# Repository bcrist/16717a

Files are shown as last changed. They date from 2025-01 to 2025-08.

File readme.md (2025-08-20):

# 16717A Logic Analyzer Redux

The HP/Agilent 16700A/B and 16702A/B logic analyzer mainframes were originally released somewhere between 1998 and 1999, and though they have now been obsolete for many years, they can still be useful for hobbyists who need to debug digital circuits with large parallel buses (especially the homebrew CPU community, who build computers from scratch, often using nothing but 7400-series logic and parallel SRAM chips).  These "boat anchors" were the last logic analyzers produced which do not use commodity PC hardware or run Windows; instead they run HP's unix variant (HP-UX) on a 150MHz PA-RISC processor.  All the operating system and analysis software is still available, and can be run from a SCSI hard drive emulator like SCSI2SD or ZuluSCSI.  And since it is just an X-windows application, you can run an X server on a modern machine with a high resolution monitor and then view the analysis software on that instead of being limited to the built-in 1024x768 LCD.

The actual triggering, sampling, and storage of waveform data is done on up to five modules.  HP/Agilent produced a variety of these, but the ones most commonly found today are:
* 16710A, 16711A, 16712A: up to 128k sample depth, 104 channels (max. 208 with 2 modules), 100MHz state analysis, 500MHz timing analysis
* 16715A, 16716A, 16717A: up to 4M sample depth, 68 channels (max. 340 with 5 modules), 333MHz state analysis, 2GHz timing analysis (except 16715A)

There's only two different PCBs used for these and the lower model numbers are effectively just software limited to a lower memory depth and can be "upgraded" by adding or removing a resistor (apart from the 16715A which lacks all the timing zoom chips).

All the 167xxA modules had plastic sliders on the bottom to prevent damage to any components on that side if not installed carefully.  Unfortunately, these rails were attached with a foam/rubber adhesive that over time either becomes corrosive, or absorbs water from the air which then becomes corrosive.  This has been documented extensively on the [EEVblog forums](https://www.eevblog.com/forum/repair/series-defect-on-agilent-167xx-boards/).  It seems this corrosion begins to appear pretty reliably around 5 years after the board was made.  As of 2025, any board which has not already had the rails removed is almost guaranteed to no longer be fully functional.  Depending on the damage, it may still be possible to repair, but if any corrosion managed to work its way into a via connecting to one of the internal signal layers, it will likely be unfixable.  I have a handful of 16717A boards like this, and multi-layer PCBs have become surprisingly affordable in recent years, so I decided to desolder all the components from one and sand down the PCB layer by layer to reverse engineer it.  You can find the scans from this in the [scans](./scans/) directory.

# Reference Design
In the [original](./original/) directory you can find my reverse-engineered version of the 16717A that is as close to the original board design as I could make it based on my scans.  Due to distortion, there may be some errors in component and trace placement, however it includes all test points from the original and should be useful when debugging failed 16717A boards.  Unfortunately there are a number of signals that I can't confidently guess at their purpose, so I just named them things like `CTRL1` etc.

# Redux Design
I wasn't happy with a number of things about the original design, so I decided to create a modified version that I think should be more reliable, and if you're going to have these boards made, it's the one I would suggest.  This version is pictured above, and the details can be found in the [redux](./redux) directory.  As of this writing, ordering a set of 5 PCBs from JLCPCB will cost between $260 - $310 depending on solder mask color and shipping selections.

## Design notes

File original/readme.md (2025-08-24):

# Original 16717A PCB Reproduction

Note: While this board design is meant to match the original as closely as possible, I have not had it manufactured or tested.  Use at your own risk.

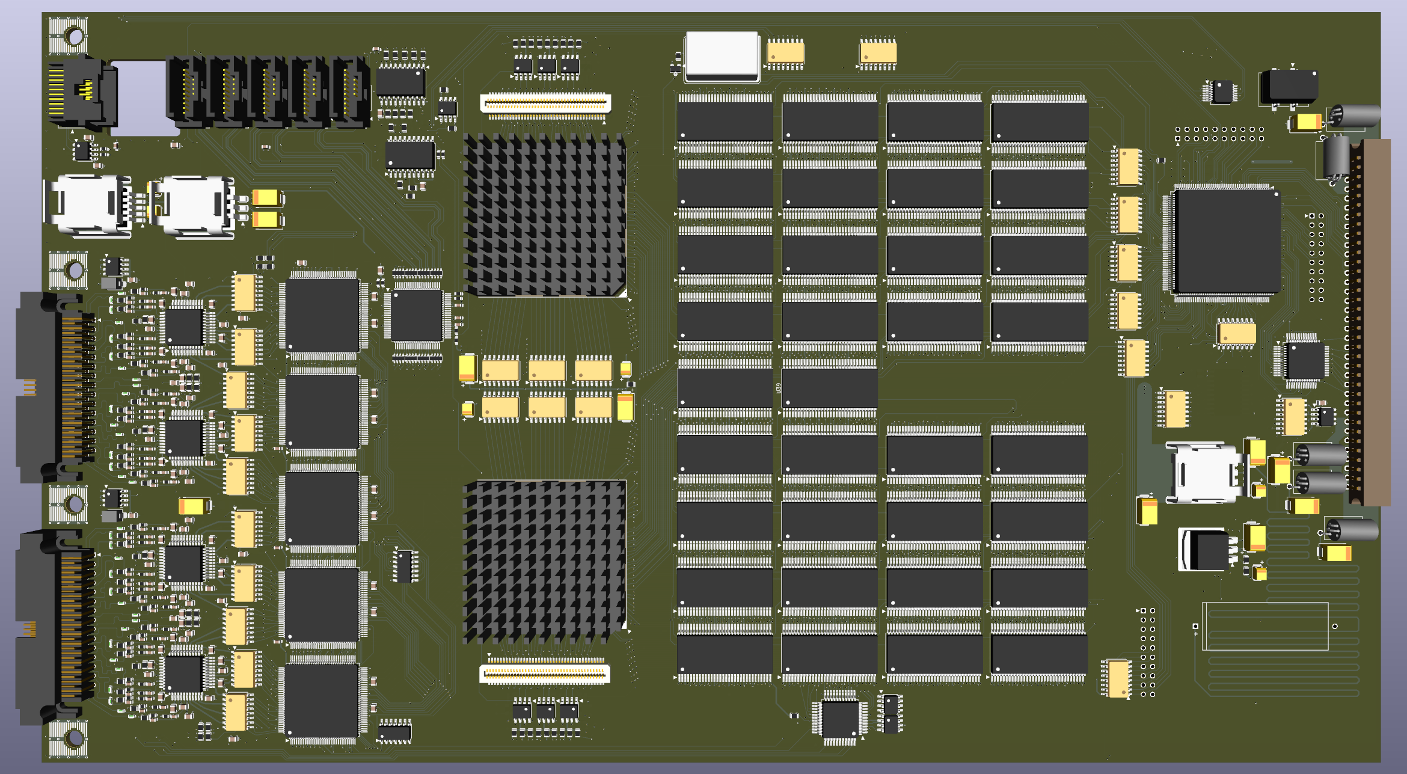
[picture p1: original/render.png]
3D Render


# Theory of Operation

You may also be interested in reading the official "Theory of Operation" section of the [Agilent manual](https://docs.alltest.net/manual/Alltest-Agilent-Keysight-16717A-ServiceManual-21826-.pdf), starting on page 146.  However I am hesitant to take anything it says at face value, because they describe some things which simply cannot be true based on the actual 16717A hardware.  I suspect that they probably started by copying the "Theory of Operation" section of a previous board (16712A maybe?) and missed some changes to how things work on the newer boards.  I'll try to note these issues below.

## Stackup
The 16717A uses an 8-layer board, four of which are signals:

* Layer 1 (top): components, signals
* Layer 2: ground
* Layer 3: +5V, -5.2V, ground
* Layer 4: signal
* Layer 5: signal
* Layer 6: +3.3V, -3.3V
* Layer 7: ground
* Layer 8 (bottom): components, signals

I wasn't able to determine individual core/prepreg thicknesses, but it didn't feel like any particular layers were significantly thicker than others, so I'm guessing the dielectric thickness of all FR4 layers is somewhere around 0.2mm.

## Input Conditioning & Comparators
Each signal coming in from the probe pods is length-matched and goes through an 0603 component which I can't identify, but they appear to be some kind of inductor.  At first I thought these might be fuses, but after looking at them under a microscope, it's clear they feature a spiral planar coil with 6 turns.  My LCR meter just says they're 0.1 ohm resistors.

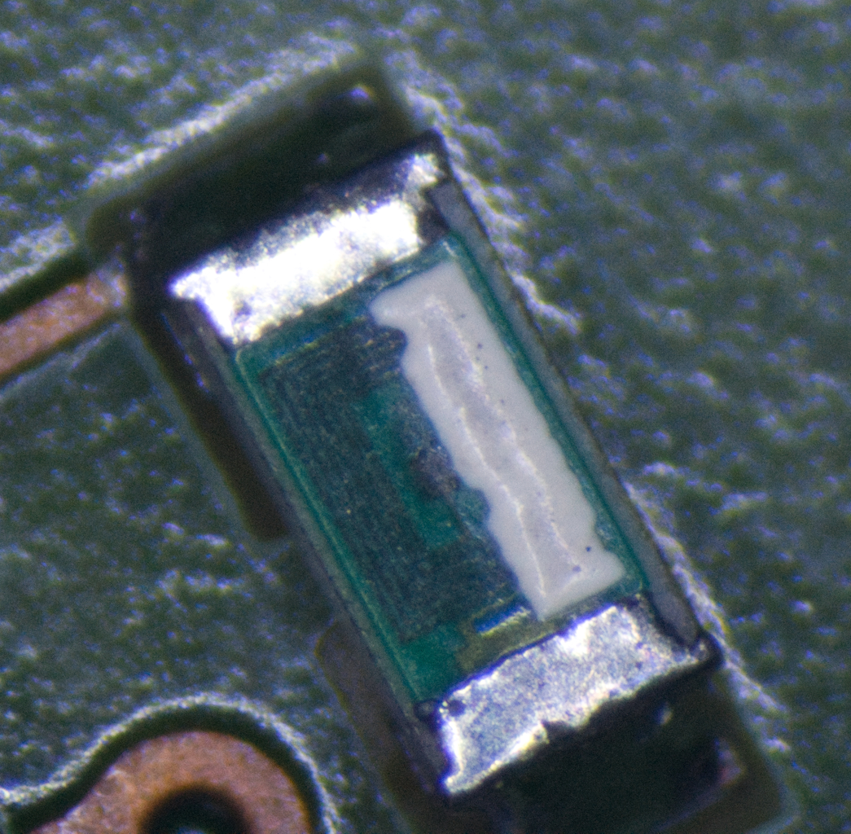
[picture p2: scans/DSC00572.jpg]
Unknown Inductor


Next each signal is terminated to ground through a 10k resistor, and further conditioned by several RC networks before being fed into one of 8 high speed comparator ASICs (part number 1NB4-5036).  Each chip has 9 signal inputs (8 data bits + 1 clock).  Each probe pod has 16 data bits and only 1 clock, so only half the comparators actually use all the inputs; the others have one input grounded.  There is also a test clock input, and when enabled it overrides the signals on all of the inputs.

The reference voltage for each chip can be configured independently, coming from an AD7841 8-channel DAC.  Interestingly, while the DAC has 8 outputs, each corresponding to one comparator chip and half of a pod's data signals, it seems there's no way in software to set half of a pod to a different threshold than the other half.

The outputs from the comparators are a rather strange ECL variant which uses `Vcc` at 3.3V and `Vee` at -5.2V.  `Vbb` is therefore approximately the same as for LVPECL; around 2.1V.  The clock signal outputs are complementary (i.e. differential) and all others are single-ended.

## Probe Power & I2C
Each pod connector receives 5V power via a TPS2011 high-side switch.  This provides current limiting in case of accidental short-circuit, and allows the power to be turned on or off as needed.  Each pod connector also contains an I2C bus, though I don't think the standard 40-pin probe cables actually connect anything to it.  The I2C bus is controlled by a PCF8584 and an analog switch to control which probe connector is currently being interrogated.

## Control FPGA & Backplane Interface
Most of the operation of the 16717A module is controlled directly by an Actel A32140DX FPGA.  The FPGA interfaces with the backplane bus, generates all of the DRAM refresh timing and control signals, and controls the two main data buses (the 16 bit memory data bus and 8 bit zoom data bus).  It also controls the comparator reference voltage DAC (through the memory data bus).

When used in a multi-module configuration, the FPGA on the master module can communicate with the FPGAs on the other modules using a 2 bit bus connected over the 20-pin ribbon cables.  This is probably some kind of serial connection; probably just a half-duplex SPI (clock + data).  It could be I2C, but if there were room to fit an I2C controller in the FPGA, they wouldn't need to use an expensive PCF8584 for the probe connector I2C bus.

The 16500A backplane bus had 8 dedicated bidirectional data lines and separate unidirectional address lines.  The 16700A service manual notes that the 16700 bus is backwards compatible with that, but has been extended to allow a 16b mode with multiplexed data/address.

There is also an 8b open collector bus, which I believe is what the service manual refers to as the IMB (inter-module bus) and is used for synchronizing triggers between modules.  This bus is interfaced with a 74FB2040 BTL buffer chip.  The FPGA drives the FB2040 TTL-level output signals, while the TTL-level input signals are sent to both of the acquisition ASICs.

## Timing Zoom Acquisition[^1]
The outputs from the comparators go through some custom resistor networks which split each signal into two.  One of the signals goes directly into the Timing Zoom chips (1NB4-5040).  These five chips each have 14 differential inputs.  For the single-ended signals (i.e. everything except the clocks) the inverting input is fed from the corresponding comparator's `Vbb` output, after it also goes through the same kind of resistor network as the signals.  I suspect these chips are mostly just high speed SRAMs with an address counter to fill them up automatically and some interface circuitry to allow them to be read out from an 8 bit bus.  The chips use only 3.3V power, and it would seem the 8 bit "zoom data bus" uses LVCMOS signaling.

Most of the zoom data bus signals are shared in common across all five chips, but each zoom acquisition chip does have one dedicated chip select (or possibly output enable?) signal, as well as a signal that's connected to one of the bits of the zoom data bus (but a different bit for each chip).  My best guess is that the latter signals are used to allow "multicast" commands to be sent to multiple chips at the same time.  This data bit signal is also delivered to each chip after being gated by a 74LVC08 chip, combining them with one of the shared control signals.  I have seen pictures of an early 16716A prototype board where the 74LVC08 chips were added dead-bug style with bodge wires, so apparently these are only there to work around some bug in the 1NB4-5040 silicon.

## Timing Zoom Clock Generation & Distribution[^1]
In order to ensure that all the timing zoom chips are synchronized (including potentially on multiple modules), they need to be clocked from the same source.  That source is a 101MHz PECL oscillator.  The signal is level shifted to LVPECL through DC-blocking capacitors and an LVPECL differential receiver, and then goes through a SY89421V PLL in 10x mode, resulting in a 1.01GHz differential LVPECL output.  That signal then goes to the HP 1821-4731 clock distribution ASIC, which buffers it out to each of the 20-pin ribbon cable connectors in the corner of the board.  It then comes back via the right-angle 20-pin connector, through another LVPECL buffer, and right back into the clock distribution ASIC again.  When using just a single board, this might seem silly, but it means that when using multiple modules, the clock from the "master" module is delivered to the clock distribution chip on each module with exactly the same propagation delay.  Finally, a pair of differential clocks are delivered to each of the five 1NB4-5050 chips.  Since the zoom clock is only 1GHz, but the timing zoom feature captures at 2GS/s, it might be that one of these clocks is just a 180-degree out of phase copy?  I don't have a scope fast enough to capture these signals, so I'm not sure.

The timing zoom distribution chip appears to be a fully bipolar design, using 5V ECL signaling for everything, except instead of the usual 5V PECL or -5V NECL schemes, it uses 3.3V `Vcc` and -1.7V `Vee`.  This is partly necessary because the zoom acquisition chips are only capable of receiving 3.3V signals, but as to why they didn't just design the part to use LVPECL with `Vee` connected to ground, I cannot guess.  Perhaps they originally designed this chip for something else where `Vcc` was 5V?

The clock distribution chip also connects to the zoom data bus, and has a bunch of control signals coming from the FPGA, but since these signals use normal TTL/CMOS signaling, they need to go through some resistor networks to massage them into something that the single-ended ECL inputs can detect.  Because of this, it is likely that this chip can't write anything back to the zoom data bus, it's likely only used to configure the zoom acquisition frequency (there is a configurable divider somewhere in there) and possibly configure how many clock pulses to generate when triggered.

There is one apparently ECL output from the zoom distribution chip.  It goes to an LM311 with the negative input held at 2.1V, and the result gets sent to the FPGA.  I have no idea what this might be used for, but it must not be anything timing sensitive, since the comparator will not react very fast.  Perhaps it's an error signal used to detect a failed oscillator/PLL?

Finally, the zoom clock distribution chip receives a signal from each of the two regular acquisition ASICs.  I suspect this is used to gate the zoom clock until the trigger condition has been detected.

## Test Clock Generation & Distribution
In addition to the differential zoom clock, the 20-pin ribbon cables also distribute a pair of LVNECL test clocks from the master module to each module.  This signal originates from the 100MHz backplane clock, divided down to either 50MHz or 25MHz by an MC10EL34 and MC100LVEL14.  Once on each module, the clocks go through a voltage divider and are sent into each of the comparator chips.  The test clock allows self tests to verify of most of the signal paths without needing any external equipment to inject signals.

## Acquisition ASICs[^2]
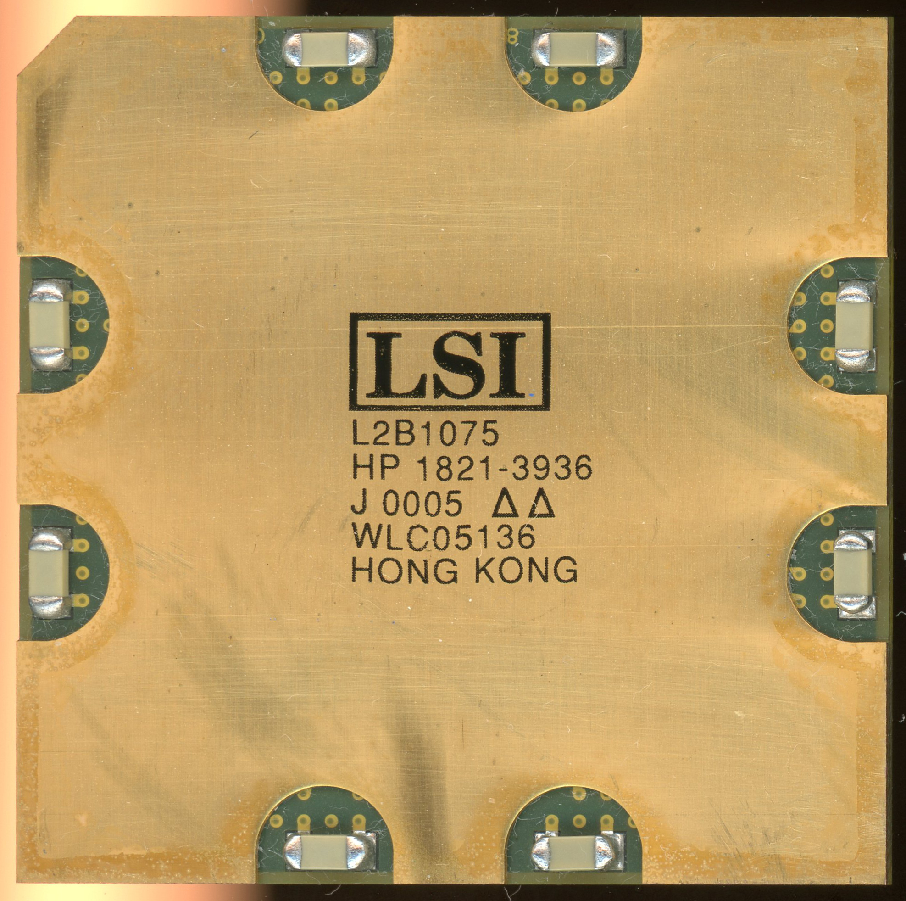
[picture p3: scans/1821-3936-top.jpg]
Top

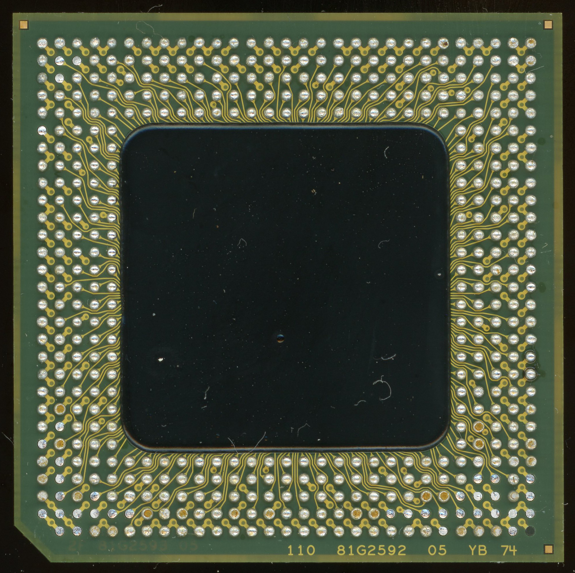
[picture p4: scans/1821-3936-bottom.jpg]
Bottom

As mentioned above, the ECL outputs from the comparators are split in two, with one signal going to the zoom chips, and the other being routed through 80-100mm of microstrip to one of the two HP 1821-3936 chips (pictured above).  Each ASIC is responsible for sampling 34 channels (32 data + 2 clocks).  The clock signals use differential signaling, while the data signals are single-ended.  The `Vbb` voltage from each comparator is delivered to the acquisition ASIC, but pulled up slightly closer to 3.3V via a 1K/10K voltage divider, so instead of ~2.1V, the ASIC sees ~2.3V, and I'm not sure why.  The ECL signals should swing between 1.7V~2.5V, so 2.3V is likely still fine as a threshold as long as there isn't much noise.  Maybe the fall time of the single-ended ECL signals is significantly slower than the rise time (due to the emitter follower in combination with 50 ohm transmission line) so they wanted a threshold as close to `Voh` as possible?

The service manual states "All four state acquisition clocks are sent to each acquisition IC, and the acquisition ICs generate their own sample clocks," however this is not true; each acquisition ASIC only directly receives two of the pod clocks.  My best guess is that they're speaking somewhat metaphorically, and the other two are "sent" indirectly via the inter-module communication buses discussed below.

It appears that each clock and data input goes through an independently programmable delay line to account for any propagation delay differences between channels.  `pv`'s `calTest`  indicates that the delay can be adjusted in increments of 114ps.  The service manual has this to say:

> Every time the user selects the RUN icon, the acquisition ICs individually perform a clock optimization before data is stored.
>
> Clock optimization involves using programmable delays in the acquisition ICs to position the master clock transition where valid data is captured. This procedure greatly reduces the effects of channel-to-channel skew and other propagation delays.

It's unclear if this is done using the test clock enabled, or with actual signal data, but either way, this would seem to imply that trace length matching the input signals isn't necessary (at least after the comparator outputs), but it seems like the 16717A board designer did try to do length matching anyway.  Or rather, they superficially tried, but then gave up.  The signals for each ASIC are mostly length matched amongst themselves, but the ones on the left side are all about 20mm shorter than the ones on the right side, and even within each side, there are a few outliers that are over 5mm different from the other traces.

The ASICs are configured using the 16 bit memory data bus.  This would include things like the aforementioned delay lines, setting up the triggering and state clock FSAs, etc.

There are a number of control signals which go between the FPGA and the ASICs, and I mostly have no idea what specifically they are used for, but some of them are probably chip select, read/write, and clock for reading/writing registers over the memory data bus.

The ASICs also receive the 100MHz backplane clock. `pv`'s `bpClkTest` indicates that these chips contain a PLL capable of generating at least a 166.67MHz clock from this signal.  It's unclear what reference `bpClkTest` is using to measure these frequencies, since the comparator test clock is also based on the backplane clock.  Perhaps one of the control signals from the FPGA is a copy of the FPGA clock?  The service manual mentions that in (non-zoom) timing analysis, a 4-phase 125MHz clock is used, and later mentions:

> Also, the Test and Clock Synchronization Circuit generates a four-phase 125-MHz sample/synchronization signal for the acquisition ICs operating in the timing acquisition mode. At fast sample rates, the synchronizing signal keeps the internal clocking of the individual acquisition ICs locked in step with the other acquisition ICs in the module.

This is patently false.  There is no stand-alone PLL or oscillator capable of generating even one 125MHz clock, let alone a four-phase clock, and the 50/25MHz test clock cannot be delivered to the acquisition chips at the same time as real signals are being observed, so if such functionality exists, presumably these clocks are generated from the PLLs internal to the ASICs, based on the 100MHz system backplane clock.

The backplane contains an 8 bit BTL bus which I suspect is used when you set up "chained" triggers between isolated modules.  These signals can be driven from the FPGA, and are buffered and sent to both of the acquisition ASICs.  I believe this bus is what is used for `pv`'s `flagTest` and possibly also the `armTest`.

## Inter-Module Communication[^2]
The two acquisition ASICs communicate with each other, and with the ASICs on other modules, via a combination of single-ended parallel buses and differential serial buses.

The parallel signals are either two 24 bit buses (based on their routing and pin assignments on the BGA packages) or three 16 bit buses (based on the output of `pv`'s `icrTest`).
Half of the bits are routed between modules on the left 80 pin mezzanine connector, and the other half on the other connector.
The signals are terminated with pullups to 1.5V, and there is a resistor network set up to provide a reference at 2/3 of this termination voltage, which makes it look a lot like GTLP signaling.  Although snooping on some of the signals while running `icrTest` shows that they are driven all the way to 0V when low.  I don't have much experience with GTLP, but my understanding is that `Vol` should be more like 0.5V, so I'm not sure if they're really using GTLP drivers or just something similar.
Oddly, the 1.5V termination voltage is generated from a linear regulator which receives 5V through a long, winding PCB trace.  I guess the intent here was that it would act like an inductor/transmission line and help reduce noise?  There is also a footprint for a huge axial electrolytic cap on the plane side of this 5V trace.  It is unpopulated on production boards, but the 16716A prototype photos show it populated.

The differential serial signals are grouped into two sets of three differential pairs, and have separate transmit and receive pins on the ASICs.  The left ASIC appears to only be capable of transmitting to the three signals on the left mezzanine connector, and the same with the right ASIC and right mezzanine connector.  The signals from the mezzanine connectors are buffered by LVPECL receivers and then routed to both ASICs, so every ASIC can listen to both "sides" of the system, even if they can only transmit on one side.  The six pins that are used to transmit on the left side are different from the six pins used on the right side, and the "unused" set from the other side of the chip is connected across to the other ASIC, but not to the mezzanine connectors.  Each ASIC "knows" whether it is left or right, so it's possible these signals are six single-ended GTLP signals rather than three complementary pairs.  It's also possible that these could be used to allow the left chip to transmit on the right mezzanine connector's differential pairs, using the right ASIC as an intermediary, and vice-versa.

It appears someone tried to length-match the differential signals from the mezzanine connectors (after going through the LVPECL buffers) so that the delay to the left and right chips is identical.  But they only matched two of the three pairs.  I suspect that these signals correspond to the "master/slave/psync" clocks mentioned in the `clksTest` description in the service manual.  Unfortunately there's exactly no discussion of what these terms mean.  One might suppose that master and slave correspond to whichever clock is configured as master/slave in the GUI, but what does "psync" stand for?  Phase synchronization maybe?  If so what exactly does that mean?

## Sample Memory
Sampled state data is stored in dual port DRAM chips (OKI MSM5416283-50), storing 4Mbit each.  There are 34 total chips (not 18 as the service guide incorrectly says) for a total of 2M samples when using all 68 channels, or 4M samples if only using half the channels.  The chips are split evenly between the two ASICs, with 17 chips connected to each via nine independent "ports," with each port consisting of 16 data bits and a clock signal.  Eight of these ports are attached to the serial access port of two memory chips (i.e. two banks), while the final port is only attached to one chip (one bank).  This means the theoretical maximum write bandwidth is 7200 Mbit/s/ASIC.  At a state clock frequency of 333MHz, with 34 channels enabled, 11322 Mbit/s would be needed, so apparently they're either overclocking these chips, or else very high clock frequencies only work with some channels disabled.

The random access DRAM port, as well as all the memory control signals, are controlled directly by the FPGA, not the acquisition ASICs.  Most of the control signals are shared in common across all 34 chips, except RAS (shared by groups of 4 or 5 chips) and CAS (independently controlled on every chip) and the QSF outputs (only connected for each ASIC's port 9 chip).

[^1]: Timing Zoom circuitry is not populated on 16715A boards.
[^2]: The two HP 1821-3936 ASICs are mostly black boxes, so this section contains a lot of supposition and guesswork.

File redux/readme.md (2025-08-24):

# 16717A Redux

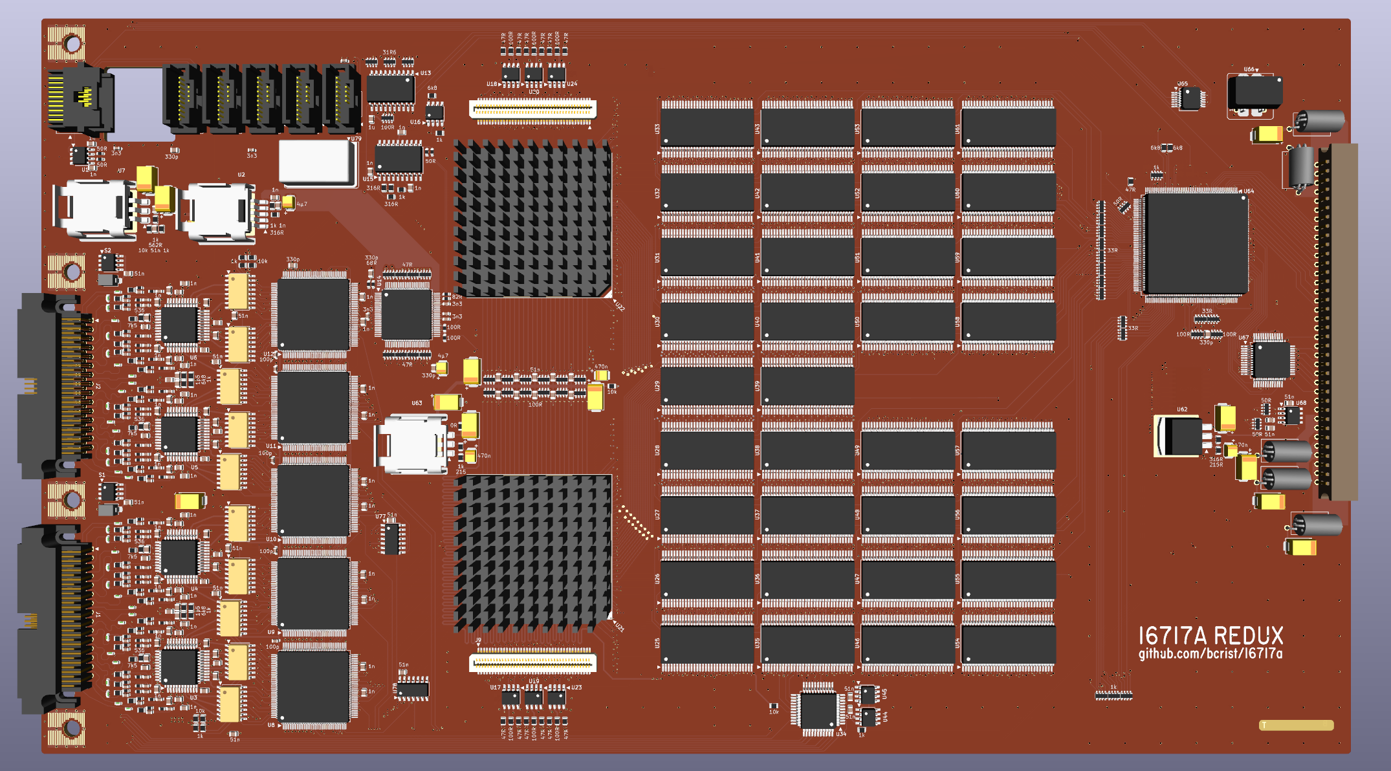
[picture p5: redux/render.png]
3D Render


# Quick Stats
* Dimensions: 366.75mm x 206mm x 1.6mm
* 10 layers
* 1250 components
* 9627 total pads
* 5392 total holes
* 3803 ~ 5048 filled & capped holes

# Tools

I would not recommend attempting to build one of these boards unless you have and know how to use the following equiment:

* 70W+ soldering station (I highly recommend something compatible with Hakko T12/T15 or JBC C210/C245 tips)
* IR preheater or temperature controlled hot plate (at least 100mm square)
* Hot air station (e.g. Quick 861DW)
* 1.27mm pitch BGA reballing tools (balls, stencil, etc.)
* Optical stereo microscope with 20x or higher magnification
* 22L ultrasonic cleaner (or larger; basket should be larger than 21cm x 37cm)

# Stackup

While reverse engineering the 16717A I noticed a lot of potential signal integrity issues:
* Most signals on the inner layers use +5V or +3.3V as a reference plane, but that is often not a power rail associated with the source and/or destination chips.
* Many signals move between front/back layers through vias without any nearby return path via.
* Many signals change between layers with different reference plane potentials without any nearby decoupling caps between the planes.

I'm sure that HP did a ton of testing to ensure there were no real world performance or EMI issues because of this, but since I don't know exactly what FR4 stackup they used, nor the dielectric constant of their core/prepreg layers, I decided it would be better to rework some things and go to a 10-layer design instead.  For small quantities of large size boards, 10-layer boards through JLCPCB are only a little more expensive than 8 layers (relatively speaking), and their default stackup for 10 layers is a bit nicer as well.

Here is the layer ordering I chose:

* Layer 1 (top): components, signals, -1.7V
* Layer 2: ground
* Layer 3: signals, +5V, -3.3V
* Layer 4: ground
* Layer 5: +3.3V, +5V, -3.3V, few signals
* Layer 6: +3.3V, +5V, -3.3V, ground
* Layer 7: ground
* Layer 8: signals, -5.2V, +3.3VP
* Layer 9: ground
* Layer 10 (bottom): components, signals

The most important goal here is to ensure that all signal layers are adjacent to ground plane layers.  No two signal layers are adjacent to each other, and all stripline layers have ground on both sides, not just one.  Additionally, since the board is quite large, the ground and power layers are symetrical to avoid any twist/bend from copper imbalance.  The inner power layers (layer 5 and 6), rather than having having one +5V and one +3.3V layer, are routed with mostly identical planes covering only areas that need 5V and +3.3V separately, to avoid coupling noise from one rail to the other.

## JLCPCB Notes

Trace widths were selected assuming JLCPCB's default 10 layer stackup (JLC10161H-2116) with 1oz outer copper and 0.5oz inner copper.  If you choose to have it manufactured elsewhere, you might need to adjust them.  For reference, JLC10161H-2116 uses four 0.2mm cores (Er = 4.6) and five 4.7mil prepregs (Er = 4.16).

All 0.3mm holes should be epoxy filled and capped (JLCPCB should do this by default for 6+ layer boards).

JLCPCB will charge an extra $15 for any design with more than 4000 holes under 0.5mm in diameter.  This is listed on their "special cases" page, but it isn't described very clearly, and at the time of writing isn't included in their automated quoting tool.  To avoid hitting this limit, most power vias in the design have been set to 0.5mm.  All of the 0.5mm holes on the board _may_ be filled and capped, but it shouldn't be a problem if they are not.

Note that even working to avoid the extra drilling charges, JLCPCB will likely charge an additional $7.50 above their quoted price for this board.  After inquiring they informed me this was due to the large number of electrical test points, though they didn't tell me exactly what the limit is before that kicks in; I decided it wasn't worth pursuing that since there's not much I could do to reduce the number of pads in the design anyway.

# Bringup

It is by no means necessary to follow these exact procedures, however if you are concerned about parts having been potentially damaged in removal from the old board, this guide allows incrementally verifying some subsystems with a minimum of time sunk into soldering hundreds of passive components.

Note: I highly recommend checking all power rails for shorts after each step below, before powering up the mainframe.  The 167xx power supplies do not seem to have short-circuit protection.  I once accidentally plugged in an original 16717A "upside-down" and ended up blowing the PSU (and maybe the FPGA on the 16717A too; it wasn't working beforehand so I can't be sure).  I was using a ribbon cable backplane extender, and forgot that the mainframe was sitting on my desk upside down.  doh!  After replacing the PSU the mainframe still works fine, thankfully.  I was afraid I might have blown the backplane interface board as well, but it seems to still work fine.

## 0. Component Harvesting

For the vast majority of the passive components, you can just use new parts of the same value.  Indeed, since I replaced a bunch of resistors and SOIC resistor networks with more modern 0612 (4x0603) resistor networks, you'll need to use new parts for those.  But almost all the semiconductors and connectors used are either custom, obsolete, or expensive, so you'll need to salvage parts from a donor board (presumably non-working only because of trace/via corrosion).  In particular, you'll need:

* Actel A32140DX FPGA.  I recommend removing this with hot air rather than trying to use low-temp solder (e.g. ChipQuik).  These are one-time-programmable parts, so you need one specifically from a 16715A, 16716A, or 16717A; don't use one from another model of logic analyzer or go looking for one on eBay, etc, or you will be disappointed.
* 2x BGA ASICs with heatsinks.  The heatsinks are attached to a brass heat spreader using a thermally conductive "tape".  Heating it up to ~100C with hot air will soften the adhesive, allowing you to begin peeling off the heatsinks with a plastic spudger.  Once the heatsinks are removed, you can use a hotplate or hot air and a preheater to remove the BGAs themselves.  Once removed, clean up the pads and reball with 0.76mm balls.  Be careful not to use too hot an iron or drag it with too much force when cleaning up the pads; the soldermask used is slightly thicker than a normal PCB's, but it seems to be somewhat softer than a normal soldermask as well.
* 8x 1NB4-5036 comparators - custom HP part; can be reused from any HP logic analyzer using 40-pin (non-differential) probes.
* 5x 1NB4-5040 zoom FISO chips - custom HP part.
* 1821-4731 zoom clock distribution chip - custom HP part.
* 34x OKI MSM5416283 dual port DRAM chips - discontinued/obsolete.  On some of my boards, these chips show signs of rust on the pins of these chips, which I don't think is related to the corrosion on the bottom of the board.  I've done my best to clean and re-tin the legs with solder, but it makes me wonder if these will be the weak link that eventually causes most boards to fail once the trace/via corrosion has been removed from the equation.  On the bright side, with 34 of them on each board, sacrificing one board should provide spares to hopefully fix many others.
* SY89421V PLL chip - discontinued/obsolete.
* SN74FB2040 BTL transceiver - obsolete, though still available via Rochester Electronics at $300+ for a few dozen chips.
* AD7841 DAC - still available at time of writing, but costs $75 each in small quantities.
* 2x AD586 voltage references - still available at time of writing, but costs $12 each in small quantites.
* PCF8584 I2C controller - At time of writing, "last time buy" at DigiKey, and costs $7 each in small quantites.  I'm not actually sure if this part is even necessary; AFAIK the probe cables normally used with the 16717A do not actually connect anything to the I2C signals.
* ECL logic chips: 1x MC10EL34, 1x MC100LVEL11, 1x MC100LVEL14, 8x MC100LVEL16.  These are all still available new, but they're quite expensive.
* 12x MRF9511LT1 NPN transistors (SOT-143 packages near the inter-board connectors).  I'm not 100% certain that this is what these are, but based on the package code and "B E E C" on the silkscreen nearby (which matches the pinout of the MRF9511LT1) I'm fairly sure.  Unfortunately these are obsolete, so you'll need to remove and reuse them or find a modern part with similar specs.
* NEL HS-2810 101 MHz oscillator - discontinued/obsolete.  One of my boards has some rust on the case of this oscillator.  If necessary, you could probably make a small daughterboard with a modern 101 MHz oscillator with differential output to replace this.
* SG-615P 19.6608MHz oscillator - discontinued/obsolete, but I have adjusted the footprint for this oscillator so that any 19.6608 MHz oscillator with TTL output should fit.
* 5x through-hole ferrites & 2x SMD ferrites - these could probably be replaced with any other ferrites, but they're not hard to remove and reuse.
* 68x unknown 0603 inductors (green with white stripe).  These are marked as fuses in the schematic but I suspect they're [actually inductors](../original/readme.md).
* 20x 4816P-B07-000 custom resistor networks.  4816P is/was a common series of SOIC resistor networks, but these are a decidedly nonstandard form, with each network containing four independent networks of three resistors each.  They could likely be replaced with discrete resistors, but it would require significant rework to the board layout.  Alternatively, you could probably make a small PCB with castellated pads in the shape of a SOIC-16 with the required discrete resistors.  But I'm just reusing these for now.
* 3x small heatsinks for LDOs.  These could probably be replaced with any other little glue-on heatsinks if you prefer.
* 4x 3M P08-080-SL-A-G mezannine connectors.  These are obsolete, but it may be possible to find some new-old-stock supplies still.  Otherwise, remove them very carefully with a preheater and relatively low-temp hot air.  I found that preheating to 150C and setting my station to 280C worked well.  Unfortunately, corrosion on the bottom on these boards sometimes destroys the gold plating on these connectors' contacts.  Of course, if you don't plan to use the board in a multi-module configuration, you can just ignore these.
* AMP 1-534204-4 backplane connector.  These are technically still actively produced, but are not stocked at any of the usual distributors, and are $19 each even when you order a whole box of 300.  So again, I chose to just remove the old one with hot air.  Alternatively, a regular 2x36 right-angle 0.1" header could be used, but the pins would need to be shifted a centimeter or so towards the front.  There is room for this, but it would require a lot of layout adjustments.
* 25 mil pitch ribbon cable & 6x connectors.  These could likely be replaced with different but similar parts.  If you're buying a non-working 16717A on eBay, etc, make sure to check if the ribbon cable is included.  I've found some of the test equipment dealers remove them inexplicably.
* 2x Probe cable connectors.  I've found some connectors with seem very similar to the ones HP/Agilent used, but not exactly compatible.  There might be some out there, or it might be possible to adjust the layout for a part with a slightly different layout, but the same connector form factor, but it's probably easiest to just salvage the original connectors.  Use kapton tape to avoid melting the part of the connector that peeks out over the edge of the board, then use hot air from the bottom side.  There are a lot of ground pins on these connectors, so using a preheater to bring the ground planes up to 100 or 150C is helpful.
* 4x PEM press-fit threaded nuts & back panel bracket.  These nuts are likely still available, but I'm not sure exactly what model number they are.  I recommend using a screw or standoff to remove these.  Hold the screw with pliers/vice-grips and rock back and forth until the inserts are free.  Note that removal will likely cause damage to the donor board.

## 1. FPGA

The first goal is to get a 16700A/B to recognize the board as a 16717A module, which indicates that the FPGA isn't completely dead, and is able to communicate with the backplane.  The main parts that need to be populated for this test are:

* The AMP 1-534204-4 backplane connector
* The +5V and +3.3V ferrites and bulk capacitors
* The Actel A32140DX FPGA (the large PQFP-208 package near the backplane connector) and some decoupling capacitors
* The 19.6608 MHz crystal oscillator which is the FPGA's main clock source
* Two of the ribbon cable connectors near the front and some associated resistors and capacitors (the FPGA needs these to determine whether it is the master or an extension board)
* The ribbon cable between the previously mentioned connectors

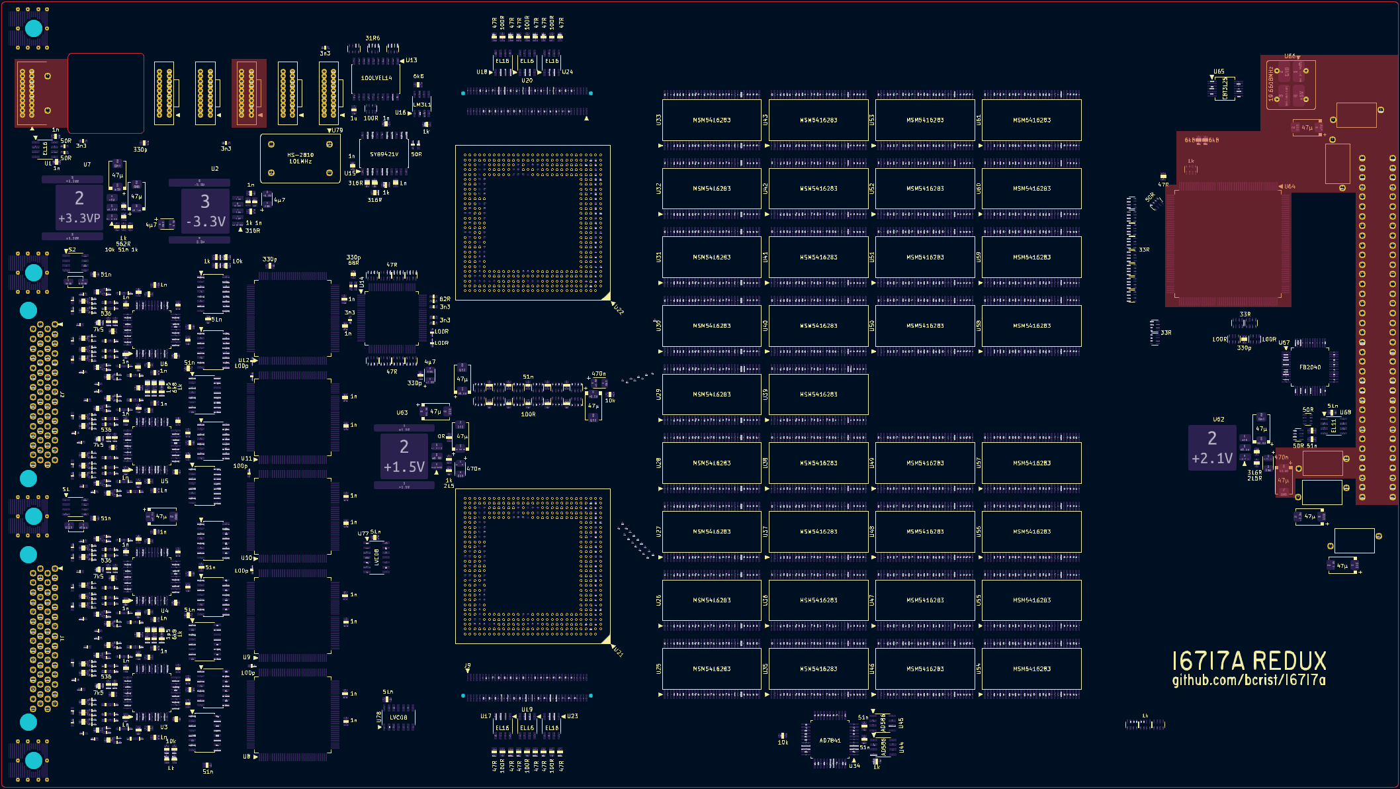
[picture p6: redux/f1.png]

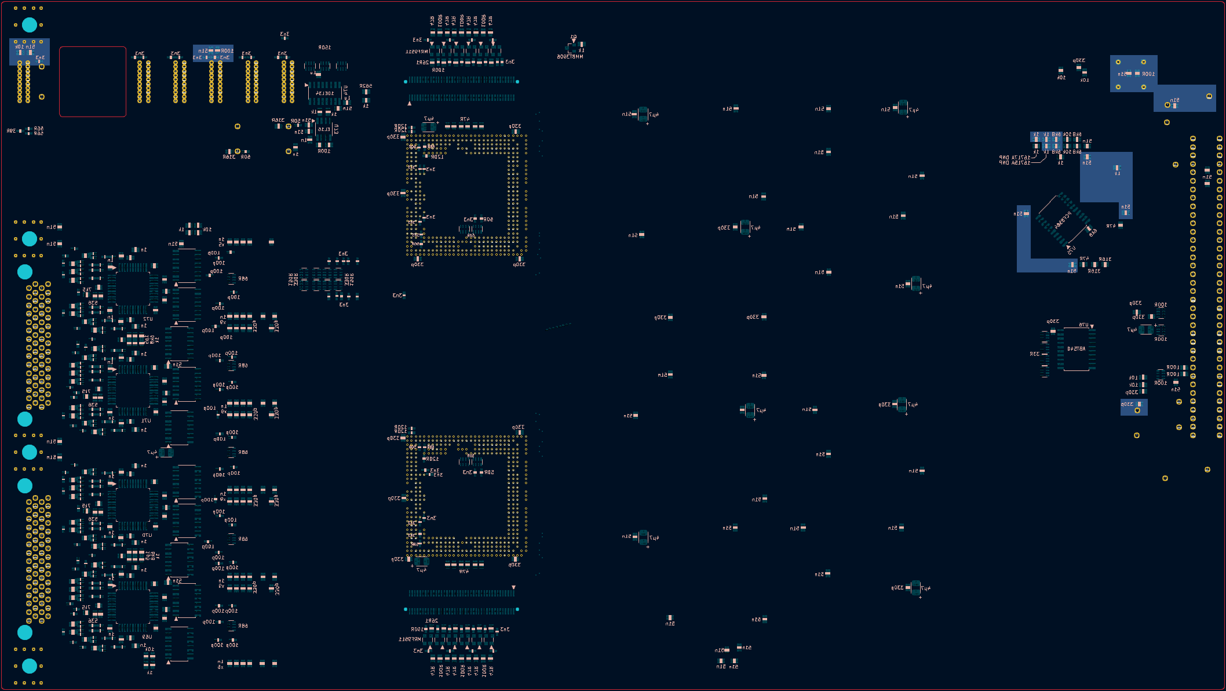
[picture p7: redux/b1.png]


Note: I don't recommend installing the back panel bracket/screws yet.  You can use zip ties to create pull loops for removing the board from a mainframe after testing.

Once these components have been populated, the board should be selectable in `pv`, but all of the tests should fail:

```
$ pv
Shared Memory Segment 204 attached at Virtual Address: 0xc0dbf000
DMA Shared Memory is mapped to Physical Address: 0x4e9b000
Second half of DMA Shared Memory is mapped to Physical Address: 0x4c57000
RPC system Initialized (Program=700016505, Version=1)
pv> l
# Model 16702B
# System Memory=256 Mbytes, PCI device=1, PCI driver=1.01
Mod CPU: System CPU Board
Mod PCI: 16702B System PCI Board
Mod A  : Empty slot
Mod B  : (0x2e) 16717A 333MHz State/2GHz Timing Zoom 2M Sample
Mod C  : Empty slot
Mod D  : Empty slot
Mod E  : Empty slot
Mod 1  : Empty slot
Mod 2  : Empty slot
pv> s b
Module index=B
pv> x modtests
Mod   B: TEST FAILED       # "vramDataTest" (1, 1, -1)
Mod   B: TEST FAILED       # "vramAddrTest" (1, 1, -1)
Mod   B: TEST FAILED       # "vramCellTest" (1, 1, -1)
Mod   B: TEST FAILED       # "vramUnloadTest" (1, 1, -1)
Mod   B: TEST FAILED       # "chipRegTest" (1, 1, -1)
Mod   B: TEST FAILED       # "bpClkTest" (1, 1, -1)
Mod   B: TEST FAILED       # "cmpTest" (1, 1, -1)
Mod   B: TEST FAILED       # "icrTest" (1, 1, -1)
Mod   B: TEST FAILED       # "flagTest" (1, 1, -1)
Mod   B: TEST FAILED       # "armTest" (1, 1, -1)
Mod   B: TEST FAILED       # "vramSerDataTest" (1, 1, -1)
Mod   B: TEST FAILED       # "vramSerCellTest" (1, 1, -1)
Mod   B: TEST FAILED       # "clksTest" (1, 1, -1)
Mod   B: TEST FAILED       # "calTest" (1, 1, -1)
Mod   B: TEST FAILED       # "zoomDataTest" (1, 1, -1)
Mod   B: TEST FAILED       # "zoomMasterTest" (1, 1, -1)
Mod   B: TEST FAILED       # "fisoRedundancyTest" (1, 1, -1)
  Mod B: Unable to Detect WRAP Flag.  Possible Board Fault.
Mod   B: TEST FAILED       # "zoomAcqTest" (1, 1, -1)
  Mod B: Unable to Detect WRAP Flag.  Possible Board Fault.
  Mod B: Unable to Detect WRAP Flag.  Possible Board Fault.
  Mod B: Unable to Detect WRAP Flag.  Possible Board Fault.
  Mod B: Unable to Detect WRAP Flag.  Possible Board Fault.
Mod   B: TEST FAILED       # "zoomChipSelTest" (1, 1, -1)
```

You may see `bpClkTest` report a pass, but it's a false-positive.  If you run the test with debug mode enabled, you can see that the test is only checking for a frequency above certain thresholds.
The PLLs mentioned are inside the acquisition ASICs, so without them populated, it's just picking up random interference.  If it happens to get a "frequency" over 158 MHz, it will consider the test successful.

```
pv> x bpClkTest
  Mod B: Measurement Did Not Complete.
  Testing 100 MHz - PLL bypass mode:
    Slot B, Chip 9: exp: > 9500000, actual: 151783694
    Slot B, Chip 8: exp: > 9500000, actual: 151783694
  Testing PLL at 166.67 MHz:
    Slot B, Chip 9: exp: >15833333, actual: 151783694
    Slot B, Chip 8: exp: >15833333, actual: 151783694
```

You may or may not see the "Unable to Detect WRAP Flag" lines, but if they do appear, they should go away once the remaining passives around the FPGA are populated.

## 2. Acquisition ASICs

By far the most difficult parts to solder are the two ASIC BGAs, so as soon as possible, we want to get them populated and verify that they haven't been destroyed by reflowing.  You may even want to do these before populating the FPGA components in the previous section.

If you're not comfortable reballing and soldering BGAs I'd suggest practicing on something less rare/useful first.  You may find the [`bga_stencil`](../bga_stencil/) directory useful when reballing the chips.  Once reballed, I found that soldering the chips with a hotplate only worked best.  Use polyimide tape to protect the soldermask while clamping the board to a hotplate (clamping is necessary to prevent any warping) and avoid using any hot air from above.  Too much heat can cause the interposer to warp slightly.  If this happens too much it may cause some of the outer balls to not make contact.  Heating only through the board itself helps prevent this.  Wait for the board to fully cool before unclamping it from the hotplate.

After soldering, use a multimeter in diode/resistance/continuity mode to check that each of the test points on the back side of the board has a solid connection to the chip.  There are also a few test points on the top side for signals that never traverse a via.

Once you are confident that all the BGA balls are attached properly, you can install the remaining components for the next test:

* Various resistors and capacitors underneath the ASICs (decoupling, pull ups, etc.)
* Optional: 3M P08-080-SL-A-G board-to-board connectors (these aren't really needed right now, but it may be easier to populate them before the various parts nearby)
* Transistors and ECL buffers near the board-to-board connectors near the edge of the board (used to synchronize clocks between the ASICs)
* Linear regulator for the +1.5V GTLP termination voltage, along with various associated resistors and capacitors
* MMBT3906 transistor and base resistor (allows FPGA to control biasing of inter-module clocks)
* 74FB2040 BTL transceiver, 74ABT540 inverting buffer, and associated passives (forwards async signals from the backplane/FPGA to the ASICs)
* ECL clock buffer for the 100 MHz backplane clock, along with associated passives and the -3.3V power rail passives
* Some additional passives near the FPGA, related to ASIC control signals

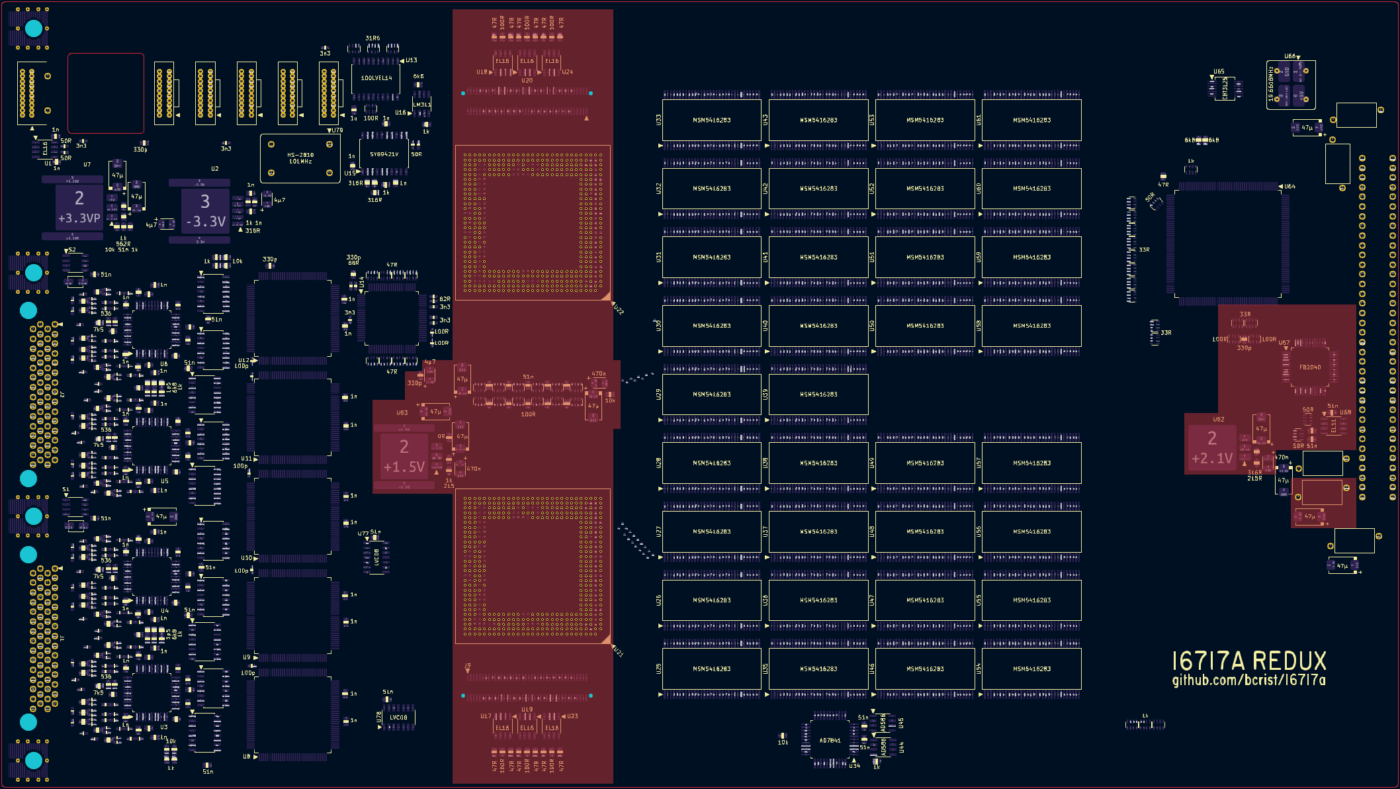
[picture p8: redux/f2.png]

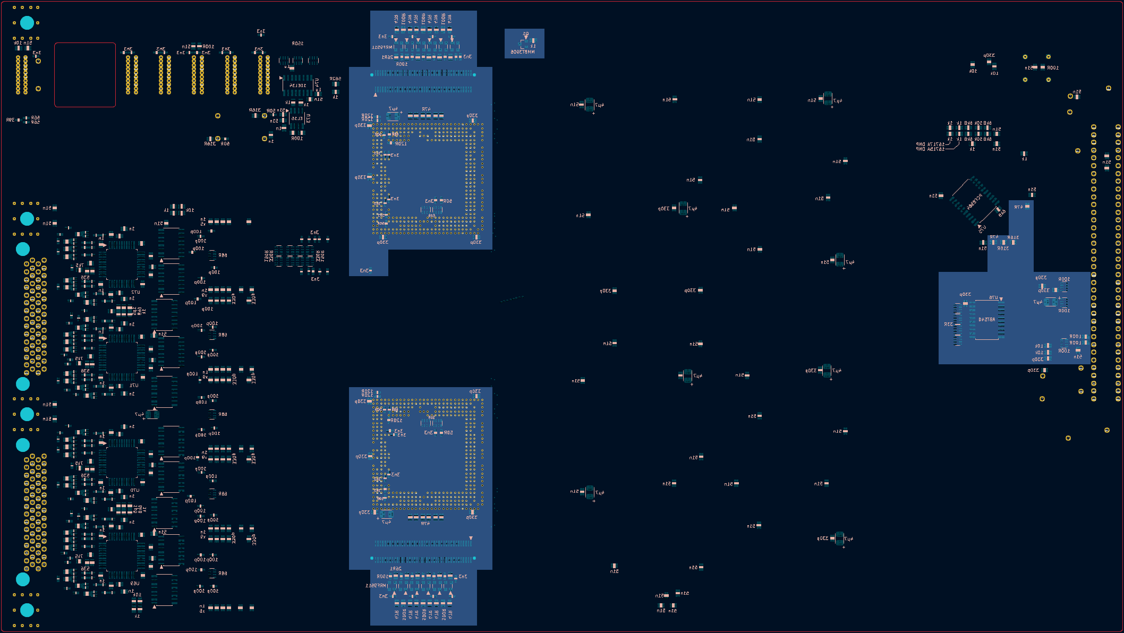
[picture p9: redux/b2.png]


It's probably not necessary for testing at this point, but I would recommend reattaching the ASIC heatsinks with some thermal compound before any attempt to power up the board.  I forgot this during one test, yet after running `pv` tests and then idling for a few minutes and shutting down the system, the heatspreaders felt cold to the touch.  Yet HP put large heatsinks on these chips for a reason.  Perhaps they only put out significant heat when running a high speed acquisition, but better to be safe than sorry.

With these components now populated, `pv` should show the board passing `chipRegTest`, `bpClkTest`, `icrTest`, `flagTest`, and `armTest`:

```
pv> x modtests
Mod   B: TEST FAILED       # "vramDataTest" (1, 1, -1)
Mod   B: TEST FAILED       # "vramAddrTest" (1, 1, -1)
Mod   B: TEST FAILED       # "vramCellTest" (1, 1, -1)
Mod   B: TEST FAILED       # "vramUnloadTest" (1, 1, -1)
Mod   B: TEST passed       # "chipRegTest" (1, 0, 1)
Mod   B: TEST passed       # "bpClkTest" (1, 0, 1)
Mod   B: TEST FAILED       # "cmpTest" (1, 1, -1)
Mod   B: TEST passed       # "icrTest" (1, 0, 1)
Mod   B: TEST passed       # "flagTest" (1, 0, 1)
Mod   B: TEST passed       # "armTest" (1, 0, 1)
Mod   B: TEST FAILED       # "vramSerDataTest" (1, 1, -1)
Mod   B: TEST FAILED       # "vramSerCellTest" (1, 1, -1)
Mod   B: TEST FAILED       # "clksTest" (1, 1, -1)
Mod   B: TEST FAILED       # "calTest" (1, 1, -1)
Mod   B: TEST FAILED       # "zoomDataTest" (1, 1, -1)
Mod   B: TEST FAILED       # "zoomMasterTest" (1, 1, -1)
Mod   B: TEST FAILED       # "fisoRedundancyTest" (1, 1, -1)
  Mod B: Unable to Detect WRAP Flag.  Possible Board Fault.
Mod   B: TEST FAILED       # "zoomAcqTest" (1, 1, -1)
  Mod B: Unable to Detect WRAP Flag.  Possible Board Fault.
  Mod B: Unable to Detect WRAP Flag.  Possible Board Fault.
  Mod B: Unable to Detect WRAP Flag.  Possible Board Fault.
  Mod B: Unable to Detect WRAP Flag.  Possible Board Fault.
Mod   B: TEST FAILED       # "zoomChipSelTest" (1, 1, -1)
```

If any of the tests shown passing above fail, try setting `d d=9` and/or `d r=9` and rerunning the failing test to get more details.  When `pv` refers to "Chip 8" it means the one closer to the ribbon cable connectors and 101MHz oscillator.  "Chip 9" refers to the ASIC closer to the AD7841 DAC.

If you see `bpClkTest` reporting a frequency of 0 for both Chip 8 and Chip 9, the problem may lie with the ECL clock buffer near the backplane connector, or one of the passives near it.  Check for shorts and verify that it has continueity to the proper ASIC pins.  If only one of the chips reports a bad frequencies, but you're reasonably certain that the clock balls are making a good connection, the ASIC may have gone bad.

If `flagTest` fails, first check the 74FB2040 transceiver or replace it if you have a spare.  If that doesn't fix the problem it's probably a bad FPGA or ASIC.

If any of the other tests fail, it's likely due to an unconnected BGA ball somewhere, or a bad ASIC.

## 3. DRAM

Next, populate the 34 DRAM chips, decoupling capacitors beneath them on the bottom side, and the RAS/CAS termination networks on the top side.

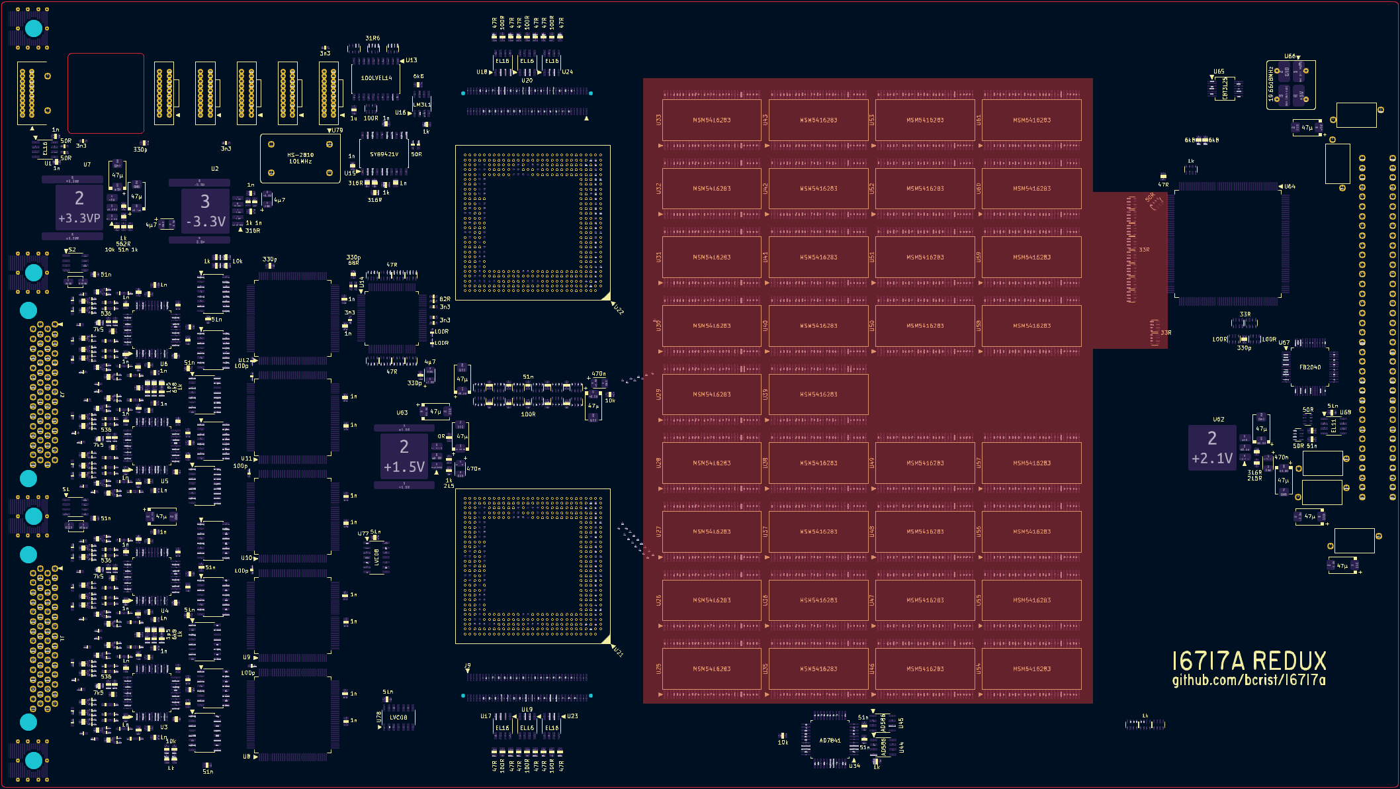
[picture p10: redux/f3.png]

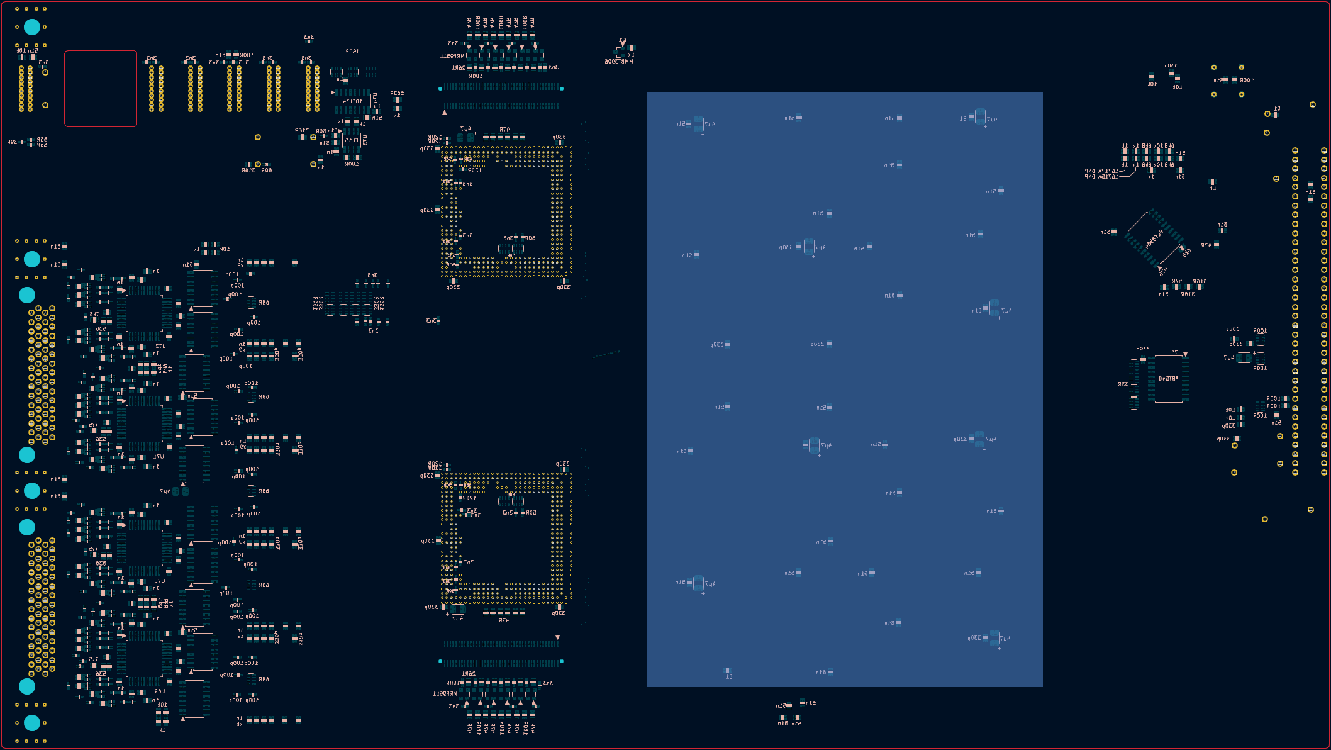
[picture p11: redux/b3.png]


Once these have been populated, `pv` should report all the `vram*` tests passing, as well as `clksTest`, and all of the previously passing tests:

```
pv> x modtests
Mod   C: TEST passed       # "vramDataTest" (1, 0, 1)
Mod   C: TEST passed       # "vramAddrTest" (1, 0, 1)
Mod   C: TEST passed       # "vramCellTest" (1, 0, 1)
Mod   C: TEST passed       # "vramUnloadTest" (1, 0, 1)
Mod   C: TEST passed       # "chipRegTest" (1, 0, 1)
Mod   C: TEST passed       # "bpClkTest" (1, 0, 1)
Mod   C: TEST FAILED       # "cmpTest" (1, 1, -1)
Mod   C: TEST passed       # "icrTest" (1, 0, 1)
Mod   C: TEST passed       # "flagTest" (1, 0, 1)
Mod   C: TEST passed       # "armTest" (1, 0, 1)
Mod   C: TEST passed       # "vramSerDataTest" (1, 0, 1)
Mod   C: TEST passed       # "vramSerCellTest" (1, 0, 1)
Mod   C: TEST passed       # "clksTest" (1, 0, 1)
Mod   C: TEST FAILED       # "calTest" (1, 1, -1)
Mod   C: TEST FAILED       # "zoomDataTest" (1, 1, -1)
Mod   C: TEST FAILED       # "zoomMasterTest" (1, 1, -1)
Mod   C: TEST FAILED       # "fisoRedundancyTest" (1, 1, -1)
Mod   C: TEST FAILED       # "zoomAcqTest" (1, 1, -1)
Mod   C: TEST FAILED       # "zoomChipSelTest" (1, 1, -1)
```

If `pv` reports errors for all chips on `vramDataTest` or `vramAddrTest`, it likely means that one or more of the memory data or address lines are shorted together, or shorted to one of the power rails.  The easiest way to track this down is with a DMM capable of precisely measuring low-ohm resistances (e.g. HP 3478A).  The location of a short will show very near 0 ohms, increasing by around 200 mOhm for the same pins on adjacent DRAMs, and up to several ohms for chips very far from the short.  Once you find the short, if there is no solder bridge, the chip is likely damaged internally.

If `pv` reports errors with only a specific chip, then the problem is likely an unconnected pin, cold solder joint, or internally broken bond wire.  this diagram may help track down which one is faulty:

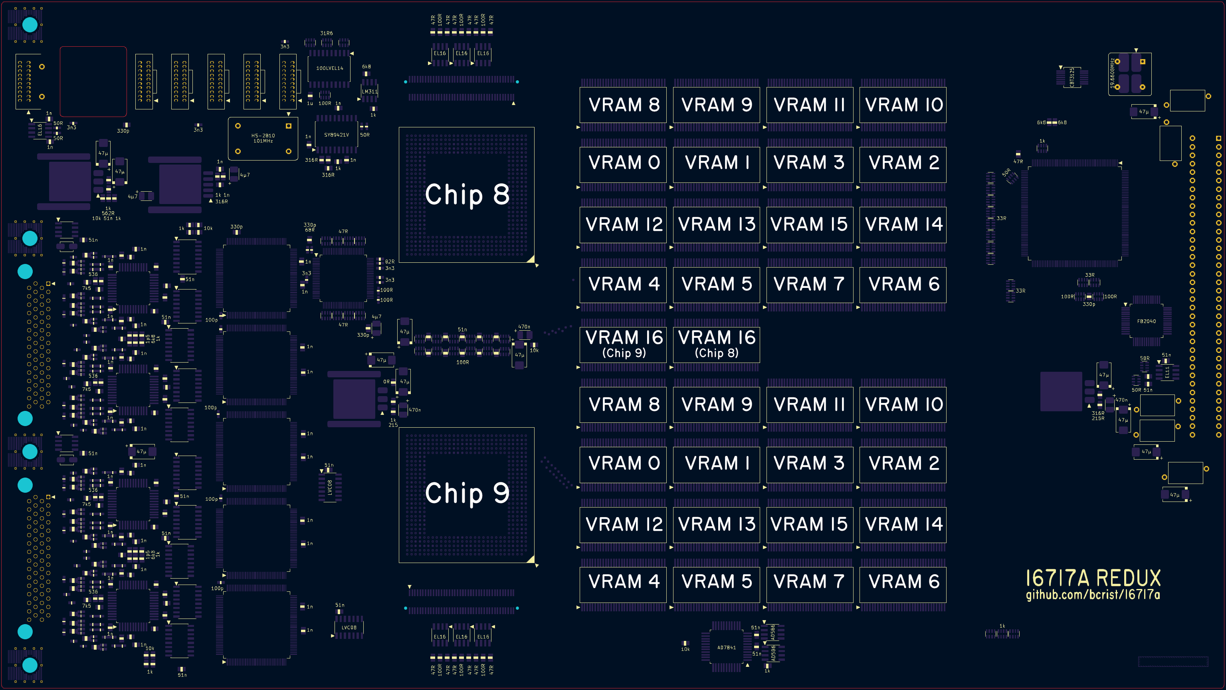
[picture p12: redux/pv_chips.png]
pv_chips


## 4. Comparators & Test Clock Generator

To make progress on the rest of the `pv` tests, we need to get the internal test clock working.  To do this we need to populate:

* The 100LVEL14 clock buffer chip and related passives
* The 10EL34 clock divider chip and related passives
* All of the 1NB4-5036 comparator chips and related passives
* A variety of miscellaneous capacitors and resistors near the comparators
* A few remaining passives on the FPGA side of the board
* All of the 4816P-B07-000 custom resistor networks
* The -5.2V backplane ferrite and bulk capacitor
* Two small capacitors on the -12V and +12V rails, under the backplane connector
* The AD7841 DAC and two AD586 references, along with their associated passives

Some other parts are not actually required by any `pv` tests, but which are best populated now:
* The PCF8584 controller and 74CBT3125 mux
* Two TPS2011 high-side switches
* The remaining ribbon cable connectors and some miscellaneous capacitors nearby
* The probe connectors

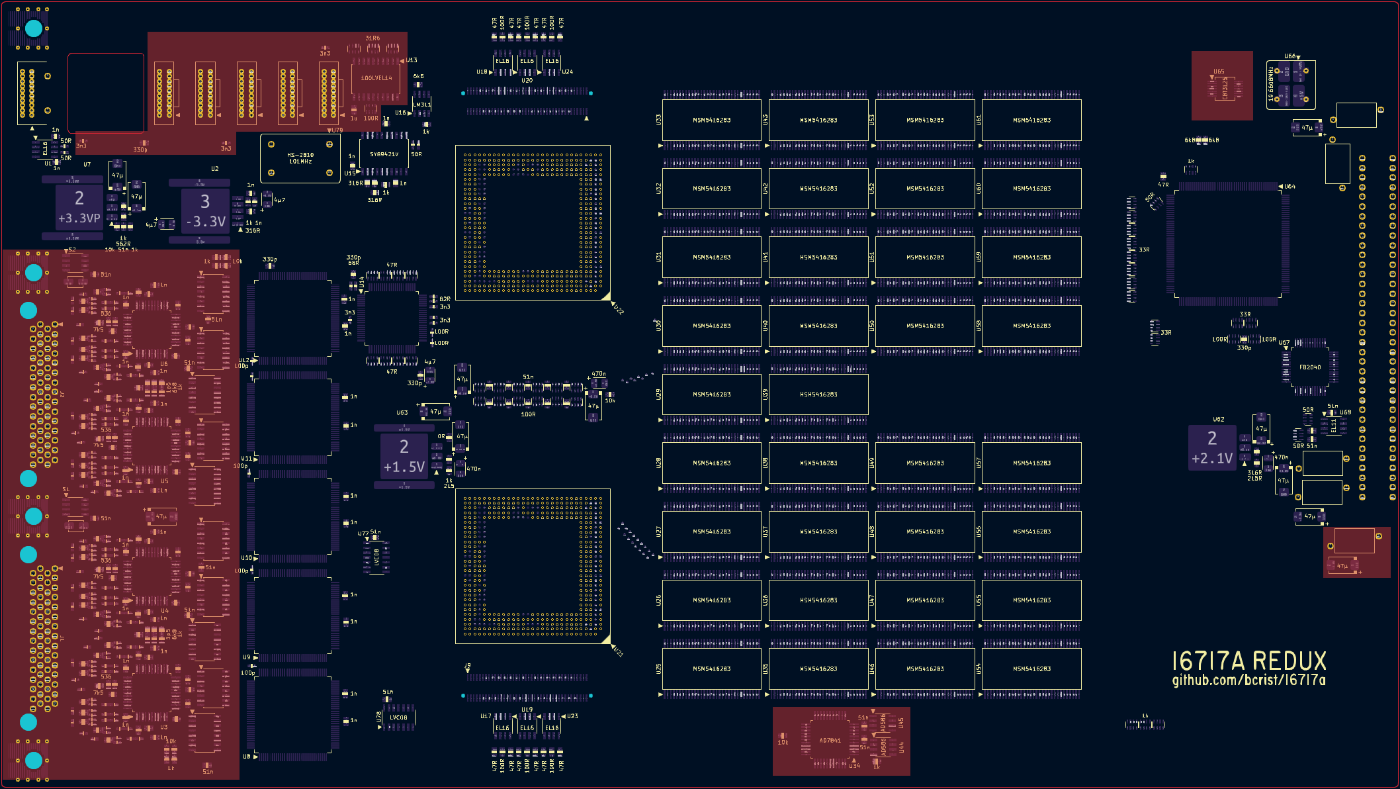
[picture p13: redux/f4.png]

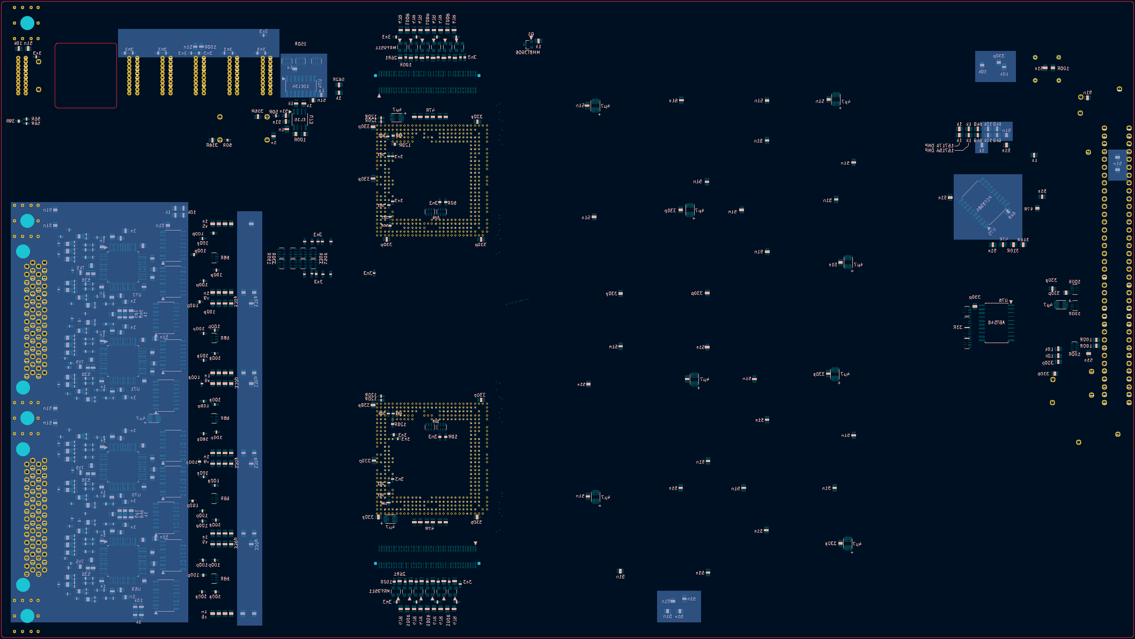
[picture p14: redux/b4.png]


`cmpTest` and `calTest` should now pass in `pv`:
```
pv> x modtests
Mod   C: TEST passed       # "vramDataTest" (1, 0, 1)
Mod   C: TEST passed       # "vramAddrTest" (1, 0, 1)
Mod   C: TEST passed       # "vramCellTest" (1, 0, 1)
Mod   C: TEST passed       # "vramUnloadTest" (1, 0, 1)
Mod   C: TEST passed       # "chipRegTest" (1, 0, 1)
Mod   C: TEST passed       # "bpClkTest" (1, 0, 1)
Mod   C: TEST passed       # "cmpTest" (1, 0, 1)
Mod   C: TEST passed       # "icrTest" (1, 0, 1)
Mod   C: TEST passed       # "flagTest" (1, 0, 1)
Mod   C: TEST passed       # "armTest" (1, 0, 1)
Mod   C: TEST passed       # "vramSerDataTest" (1, 0, 1)
Mod   C: TEST passed       # "vramSerCellTest" (1, 0, 1)
Mod   C: TEST passed       # "clksTest" (1, 0, 1)
Mod   C: TEST passed       # "calTest" (1, 0, 1)
Mod   C: TEST FAILED       # "zoomDataTest" (1, 1, -1)
Mod   C: TEST FAILED       # "zoomMasterTest" (1, 1, -1)
Mod   C: TEST FAILED       # "fisoRedundancyTest" (1, 1, -1)
Mod   C: TEST FAILED       # "zoomAcqTest" (1, 1, -1)
Mod   C: TEST FAILED       # "zoomChipSelTest" (1, 1, -1)
```

At this point, the only parts not populated should be zoom-related, and we effectively have a 16715A board that thinks it's a 16717A.  In fact, if you move the identification resistor to the 16715A setting, you'll now see all the `pv` tests pass.

### `cmpTest` Debugging

If you decide to test with only some of the comparators populated, make sure that you do populate all four of the termination networks for the 50MHz test clock.  Otherwise reflections may cause issues even on the comparators that you have populated.

Note: The output of `cmpTest` with debug result logging enabled can be really useful, but it can also be tricky to decipher.  At first glance, it seems like there's way too much output.  It can be helpful to see what it looks like when none of the comparators are populated:
```
pv> d r=9
debugLevel=0, mode=0, resultLevel=9
pv> x cmpTest
  Mod C: Measurement Did Not Complete.
  Check POD1 Thresholds:
    Slot C, Chip 9: . ........ ........  . ........ ........  Cal Clk No Act.
    Slot C, Chip 8: . ........ ........  . ........ ........  Cal Clk No Act.
    Slot C, Chip 9: . ........ ........  B BBBBBBBB BBBBBBBB  Cal Clk Levels
    Slot C, Chip 8: . ........ ........  . ........ ........  Cal Clk Levels
    Slot C, Chip 9: . ........ ........  B BBBBBBBB BBBBBBBB  Cal Clk Activity
    Slot C, Chip 8: . ........ ........  . ........ ........  Cal Clk Activity
  Check POD2 Thresholds:
    Slot C, Chip 9: . ........ ........  . ........ ........  Cal Clk No Act.
    Slot C, Chip 8: . ........ ........  . ........ ........  Cal Clk No Act.
    Slot C, Chip 9: B BBBBBBBB BBBBBBBB  . ........ ........  Cal Clk Levels
    Slot C, Chip 8: . ........ ........  . ........ ........  Cal Clk Levels
    Slot C, Chip 9: B BBBBBBBB BBBBBBBB  . ........ ........  Cal Clk Activity
    Slot C, Chip 8: . ........ ........  . ........ ........  Cal Clk Activity
  Check POD3 Thresholds:
    Slot C, Chip 9: . ........ ........  . ........ ........  Cal Clk No Act.
    Slot C, Chip 8: . ........ ........  . ........ ........  Cal Clk No Act.
    Slot C, Chip 9: . ........ ........  . ........ ........  Cal Clk Levels
    Slot C, Chip 8: . ........ ........  B BBBBBBBB BBBBBBBB  Cal Clk Levels
    Slot C, Chip 9: . ........ ........  . ........ ........  Cal Clk Activity
    Slot C, Chip 8: . ........ ........  B BBBBBBBB BBBBBBBB  Cal Clk Activity
  Check POD4 Thresholds:
    Slot C, Chip 9: . ........ ........  . ........ ........  Cal Clk No Act.
    Slot C, Chip 8: . ........ ........  . ........ ........  Cal Clk No Act.
    Slot C, Chip 9: . ........ ........  . ........ ........  Cal Clk Levels
    Slot C, Chip 8: B BBBBBBBB BBBBBBBB  . ........ ........  Cal Clk Levels
    Slot C, Chip 9: . ........ ........  . ........ ........  Cal Clk Activity
    Slot C, Chip 8: B BBBBBBBB BBBBBBBB  . ........ ........  Cal Clk Activity
> Slot C: Comparator Test Failed!
```
We can see that it tests each pod individually, and each each test consists of several parts: first testing that all the signals for the pod report high/low when the threshold voltage is well above or below the test clock signal ("Cal Clk No Act." and "Cal Clk Levels") and only then testing that the 50MHz test clock signal is seen on all signals of the pod when the threshold voltage is set in the middle of the test clock ("Cal Clk Activity").  In all three cases, all the comparators for other pods have their thresholds configured so that no signals are seen, so if you see `B` for any of the `.` spots above, you probably have a bad comparator or DAC, or maybe a shorted resistor, rather than an open circuit on one of your signal lines.

If there's a problem with the test clock generation, but the DAC is working, you'll see something like this:
```
pv> x cmpTest
  Mod B: Measurement Did Not Complete.
  Check POD1 Thresholds:
    Slot B, Chip 9: . ........ ........  . ........ ........  Cal Clk No Act.
    Slot B, Chip 8: . ........ ........  . ........ ........  Cal Clk No Act.
    Slot B, Chip 9: . ........ ........  . ........ ........  Cal Clk Levels
    Slot B, Chip 8: . ........ ........  . ........ ........  Cal Clk Levels
    Slot B, Chip 9: . ........ ........  B BBBBBBBB BBBBBBBB  Cal Clk Activity
    Slot B, Chip 8: . ........ ........  . ........ ........  Cal Clk Activity
  Check POD2 Thresholds:
    Slot B, Chip 9: . ........ ........  . ........ ........  Cal Clk No Act.
    Slot B, Chip 8: . ........ ........  . ........ ........  Cal Clk No Act.
    Slot B, Chip 9: . ........ ........  . ........ ........  Cal Clk Levels
    Slot B, Chip 8: . ........ ........  . ........ ........  Cal Clk Levels
    Slot B, Chip 9: B BBBBBBBB BBBBBBBB  . ........ ........  Cal Clk Activity
    Slot B, Chip 8: . ........ ........  . ........ ........  Cal Clk Activity
  Check POD3 Thresholds:
    Slot B, Chip 9: . ........ ........  . ........ ........  Cal Clk No Act.
    Slot B, Chip 8: . ........ ........  . ........ ........  Cal Clk No Act.
    Slot B, Chip 9: . ........ ........  . ........ ........  Cal Clk Levels
    Slot B, Chip 8: . ........ ........  . ........ ........  Cal Clk Levels
    Slot B, Chip 9: . ........ ........  . ........ ........  Cal Clk Activity
    Slot B, Chip 8: . ........ ........  B BBBBBBBB BBBBBBBB  Cal Clk Activity
  Check POD4 Thresholds:
    Slot B, Chip 9: . ........ ........  . ........ ........  Cal Clk No Act.
    Slot B, Chip 8: . ........ ........  . ........ ........  Cal Clk No Act.
    Slot B, Chip 9: . ........ ........  . ........ ........  Cal Clk Levels
    Slot B, Chip 8: . ........ ........  . ........ ........  Cal Clk Levels
    Slot B, Chip 9: . ........ ........  . ........ ........  Cal Clk Activity
    Slot B, Chip 8: B BBBBBBBB BBBBBBBB  . ........ ........  Cal Clk Activity
> Slot B: Comparator Test Failed!
```
Check the 100LVEL14, 10EL34, surrounding passives, and the -3.3V and -5.1V rails.

After these first three tests, `cmpTest` turns off the test clock signal and verifies that none of the actual input signals are toggling, and verifies that the termination networks are pulling them all to ground.  If you leave the signal inputs floating, you'll likely see something like this:

```
pv> x cmpTest
  Mod C: Measurement Did Not Complete.
  Check POD1 Thresholds:
    Slot C, Chip 9: . ........ ........  . ........ ........  Cal Clk No Act.
    Slot C, Chip 8: . ........ ........  . ........ ........  Cal Clk No Act.
    Slot C, Chip 9: . ........ ........  . ........ ........  Cal Clk Levels
    Slot C, Chip 8: . ........ ........  . ........ ........  Cal Clk Levels
    Slot C, Chip 9: . ........ ........  . ........ ........  Cal Clk Activity
    Slot C, Chip 8: . ........ ........  . ........ ........  Cal Clk Activity
  Check POD2 Thresholds:
    Slot C, Chip 9: . ........ ........  . ........ ........  Cal Clk No Act.
    Slot C, Chip 8: . ........ ........  . ........ ........  Cal Clk No Act.
    Slot C, Chip 9: . ........ ........  . ........ ........  Cal Clk Levels
    Slot C, Chip 8: . ........ ........  . ........ ........  Cal Clk Levels
    Slot C, Chip 9: . ........ ........  . ........ ........  Cal Clk Activity
    Slot C, Chip 8: . ........ ........  . ........ ........  Cal Clk Activity
  Check POD3 Thresholds:
    Slot C, Chip 9: . ........ ........  . ........ ........  Cal Clk No Act.
    Slot C, Chip 8: . ........ ........  . ........ ........  Cal Clk No Act.
    Slot C, Chip 9: . ........ ........  . ........ ........  Cal Clk Levels
    Slot C, Chip 8: . ........ ........  . ........ ........  Cal Clk Levels
    Slot C, Chip 9: . ........ ........  . ........ ........  Cal Clk Activity
    Slot C, Chip 8: . ........ ........  . ........ ........  Cal Clk Activity
  Check POD4 Thresholds:
    Slot C, Chip 9: . ........ ........  . ........ ........  Cal Clk No Act.
    Slot C, Chip 8: . ........ ........  . ........ ........  Cal Clk No Act.
    Slot C, Chip 9: . ........ ........  . ........ ........  Cal Clk Levels
    Slot C, Chip 8: . ........ ........  . ........ ........  Cal Clk Levels
    Slot C, Chip 9: . ........ ........  . ........ ........  Cal Clk Activity
    Slot C, Chip 8: . ........ ........  . ........ ........  Cal Clk Activity
  Check POD1 Thresholds:
    Slot C, Chip 9: . ........ ........  . ........ ........  Ext Data No Act.
    Slot C, Chip 8: . ........ ........  . ........ ........  Ext Data No Act.
    Slot C, Chip 9: . ........ ........  B BBBBB.BB BBB...BB  Ext Data Levels
    Slot C, Chip 8: . ........ ........  . ........ ........  Ext Data Levels
  Check POD2 Thresholds:
    Slot C, Chip 9: . ........ ........  . ........ ........  Ext Data No Act.
    Slot C, Chip 8: . ........ ........  . ........ ........  Ext Data No Act.
    Slot C, Chip 9: B BBB..BBB BBB...BB  . ........ ........  Ext Data Levels
    Slot C, Chip 8: . ........ ........  . ........ ........  Ext Data Levels
  Check POD3 Thresholds:
    Slot C, Chip 9: . ........ ........  . ........ ........  Ext Data No Act.
    Slot C, Chip 8: . ........ ........  . ........ ........  Ext Data No Act.
    Slot C, Chip 9: . ........ ........  . ........ ........  Ext Data Levels
    Slot C, Chip 8: . ........ ........  B BBB...BB BBB...BB  Ext Data Levels
  Check POD4 Thresholds:
    Slot C, Chip 9: . ........ ........  . ........ ........  Ext Data No Act.
    Slot C, Chip 8: . ........ ........  . ........ ........  Ext Data No Act.
    Slot C, Chip 9: . ........ ........  . ........ ........  Ext Data Levels
    Slot C, Chip 8: B BBBBBBBB BBBBBBBB  . ........ ........  Ext Data Levels
> Slot C: Comparator Test Failed!
```

## 5. Timing Zoom

Once everything else is working, we can add the timing zoom components:

* 1NB4-5040 zoom FISO chips (5x)
* 74LVC08 quad AND gates (2x)
* 1821-4731 zoom clock distribution chip
* LM311 comparator
* NEL HS-2810 ECL zoom reference oscillator
* 100LVEL16 zoom reference clock buffer
* SY89421V zoom clock PLL
* 100LVEL16 zoom clock buffer (after ribbon cable)
* +3.3V and -1.7V linear regulators for the PLL and zoom clock chips
* All remaining passives (except the 16717A board identification resistor)

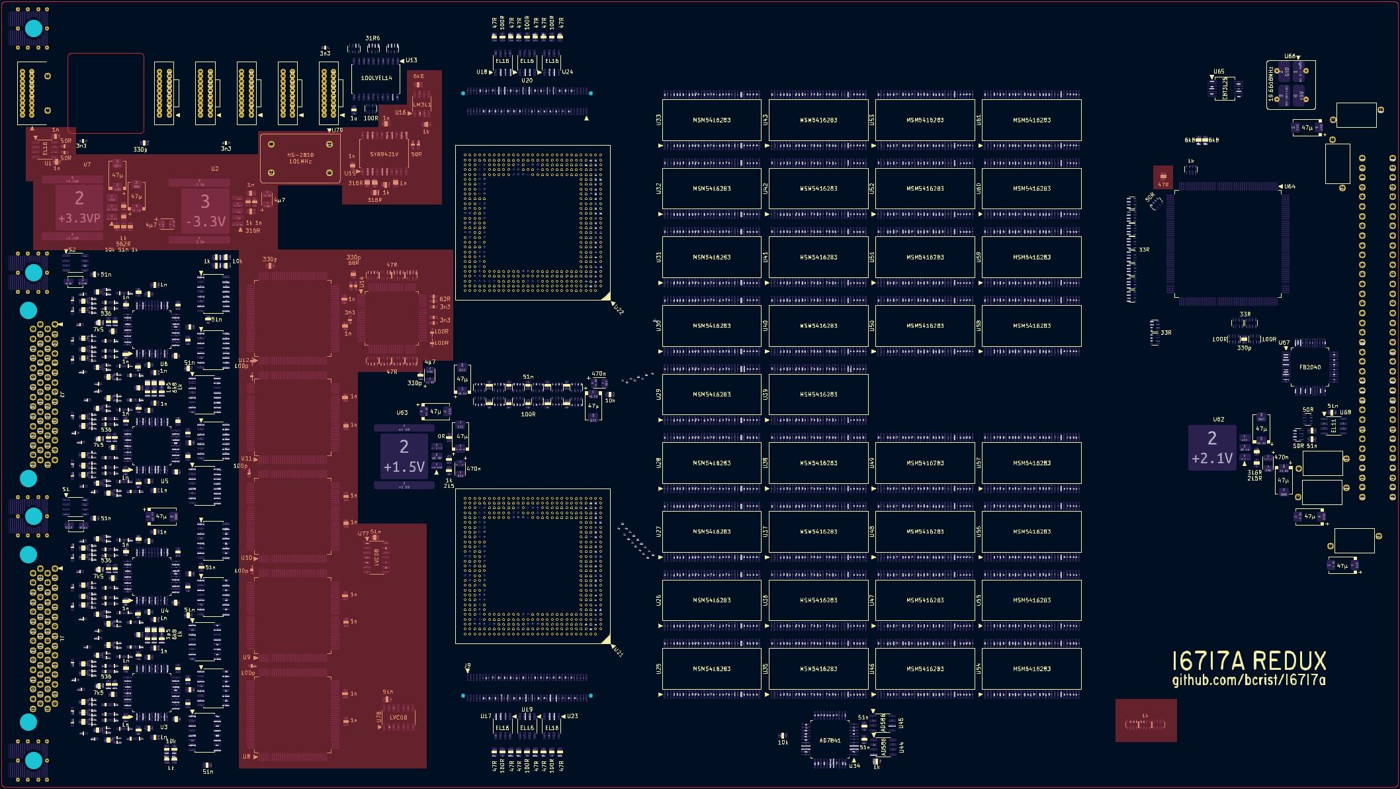
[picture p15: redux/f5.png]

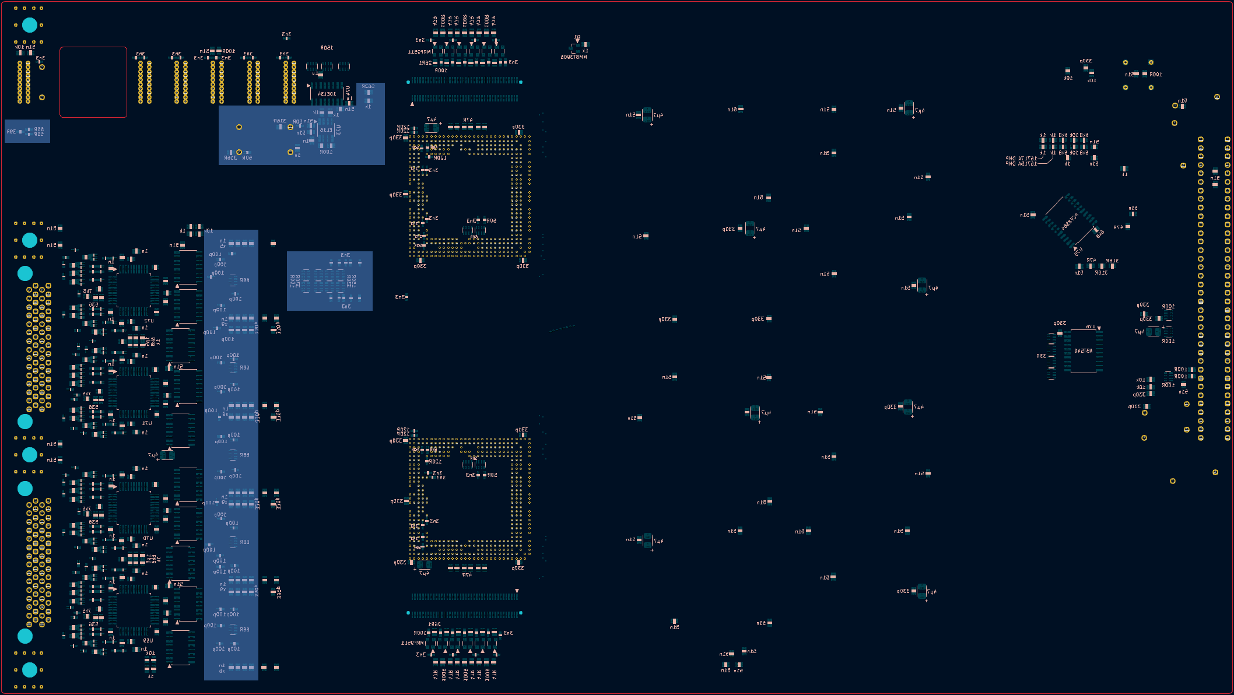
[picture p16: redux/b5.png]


Once everything is complete, cross your fingers and hope that `pv` shows no failures:

```
pv> x modtests
Mod   C: TEST passed       # "vramDataTest" (1, 0, 1)
Mod   C: TEST passed       # "vramAddrTest" (1, 0, 1)
Mod   C: TEST passed       # "vramCellTest" (1, 0, 1)
Mod   C: TEST passed       # "vramUnloadTest" (1, 0, 1)
Mod   C: TEST passed       # "chipRegTest" (1, 0, 1)
Mod   C: TEST passed       # "bpClkTest" (1, 0, 1)
Mod   C: TEST passed       # "cmpTest" (1, 0, 1)
Mod   C: TEST passed       # "icrTest" (1, 0, 1)
Mod   C: TEST passed       # "flagTest" (1, 0, 1)
Mod   C: TEST passed       # "armTest" (1, 0, 1)
Mod   C: TEST passed       # "vramSerDataTest" (1, 0, 1)
Mod   C: TEST passed       # "vramSerCellTest" (1, 0, 1)
Mod   C: TEST passed       # "clksTest" (1, 0, 1)
Mod   C: TEST passed       # "calTest" (1, 0, 1)
Mod   C: TEST passed       # "zoomDataTest" (1, 0, 1)
Mod   C: TEST passed       # "zoomMasterTest" (1, 0, 1)
Mod   C: TEST passed       # "fisoRedundancyTest" (1, 0, 1)
Mod   C: TEST passed       # "zoomAcqTest" (1, 0, 1)
Mod   C: TEST passed       # "zoomChipSelTest" (1, 0, 1)
```

There's only two things left to test now:
* Testing the board with real probes and signals.  I'll let you decide exactly how you want to do that.  If `pv` doesn't report any errors, but something isn't working, it's likely either a faulty comparator chip, a problem with one of the input filtering networks, or a bad probe/cable.
* Testing the board when used in a multi-card configuration.  Make sure both/all boards pass all `pv` tests in master configuration before attempting to use them together.  If `pv` reports errors in a multi-card configuration, but not when the boards are all masters, it probably means there's a problem with the circuitry near the board-to-board connectors, or the FFC connectors/cables themselves.

Once you're sure a board is fully working, you may want to remove the ASIC heatsinks and reapply them with thermal adhesive rather than regular thermal compound, to avoid the chance of them falling off if the mainframe is moved while the board is inside.  If you haven't yet installed the back panel bracket, do that now as well.

# Full Change List

* Stackup changed to 10 layers and added layer ID area in lower right corner
* Adjusted trace widths for JLCPCB's 10 layer stackup
* Removed debug connectors and test points
* BGA escapement and other areas use via-in-pad (epoxy filled vias)
* Added test points for electrically checking BGA connections after reflow 
* Added return path vias near signals that change layers, where possible
* Replaced almost all SOIC resistor packs and some discrete resistors with 4x0603 resistor arrays (except custom comparator output networks)
* Moved zoom oscillator closer to PLL
* Adjusted FPGA oscillator footprint to accept alternative packages (including DIP-8), since SG-615P is obsolete and I have a few boards where corrosion got to it
* Moved 1.5V ICR termination regulator to be adjacent to the ASICs that use it
* Moved zoom data bus to stay almost entirely on one inner layer and not to wrap around both edges of the board
* Zoom clocks coming from distribution chip are now exclusively on inner stripline layers
* LM2991 (-1.7V regulator for zoom distribution chip) now delivers power via a plane on the top layer
* ON/OFF pin on LM2991 is tied to GND pin as datasheet recommends
* ICR bus between ASICs is now on top and one internal layer, rather than top and bottom layers, freeing up the bottom layer for more flexible component placement & routing
* Inter-chip clock lines are now correctly length-matched
* Significantly changed power plane layout: 2 middle layers mostly devoted to +5V and +3.3V, -5.2V is on layer 8
* Unused inputs on 74LVC08 are grounded
* Removed length matching on ECL signals from comparators to acquisition BGAs.  Not all signals were matched to the same length, and the delay is automatically tuned for each signal individually anyway.
* Increased the values of a few ceramic decoupling caps
* Probe connectors now have mounting holes in case additional strain relief is desired

I also considered reworking some of the LDOs; in particular the LM2991 which is using +3.3VP as a virtual ground, since the LM2991 can't regulate close to its ground reference.  It seems strange that they didn't just use the 3-terminal LM337 instead, since -1.7V shouldn't be a problem for it.  The parts do have slightly different noise characteristics, but I can't see that being a problem here, as ECL is pretty tolerant to noise on `Vee`.  In the end, I decided to keep all the LDO circuits as-is, except for some layout adjustments.

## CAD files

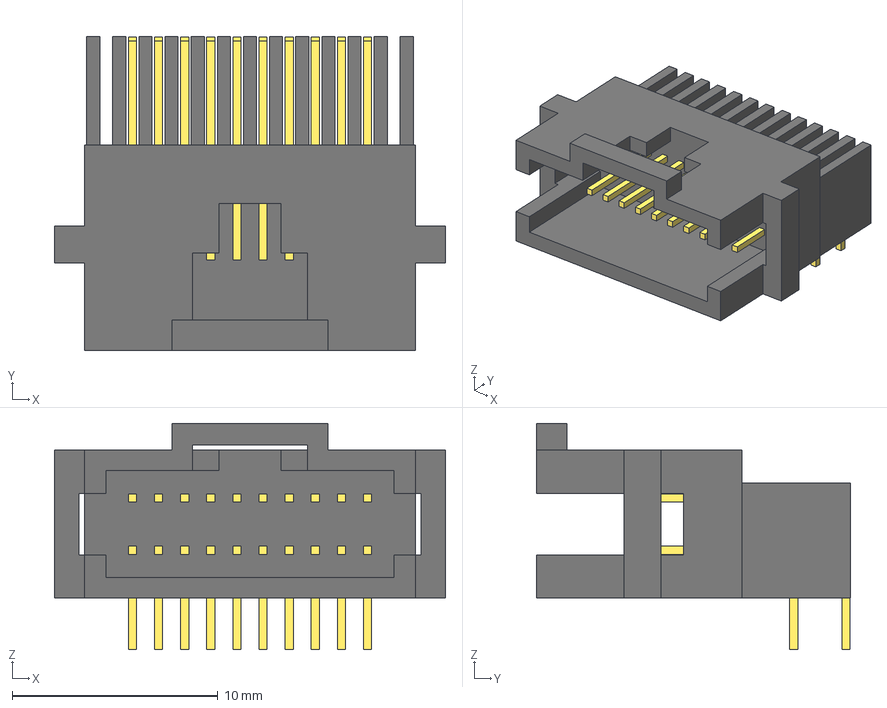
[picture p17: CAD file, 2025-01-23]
3d/2x10_horizontal.step
19.0 x 15.3 x 11.0 mm

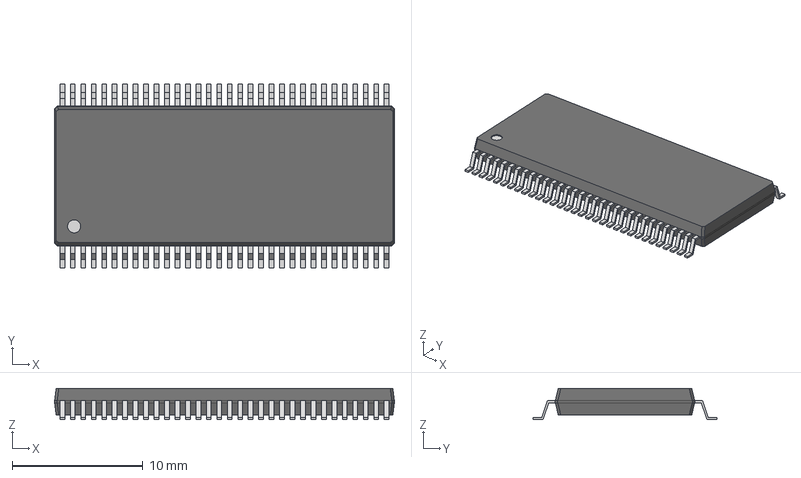
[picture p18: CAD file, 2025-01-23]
3d/ssop64.step
26.0 x 14.1 x 2.40 mm

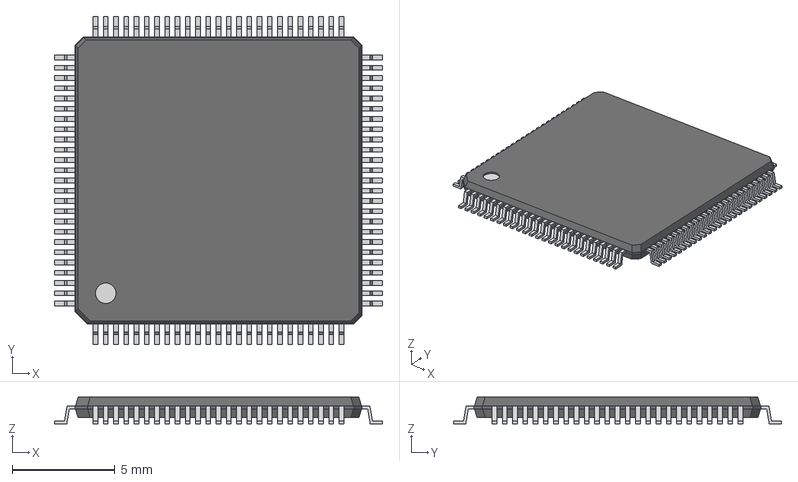
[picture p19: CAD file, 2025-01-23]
3d/tqfp100.step
16.0 x 16.0 x 1.30 mm

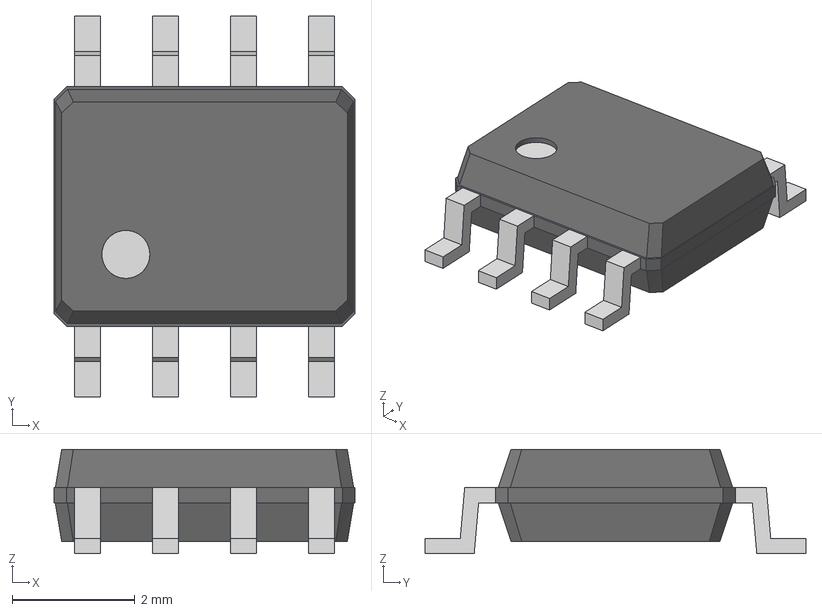
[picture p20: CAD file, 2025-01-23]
3d/soic8.step
4.90 x 6.20 x 1.70 mm

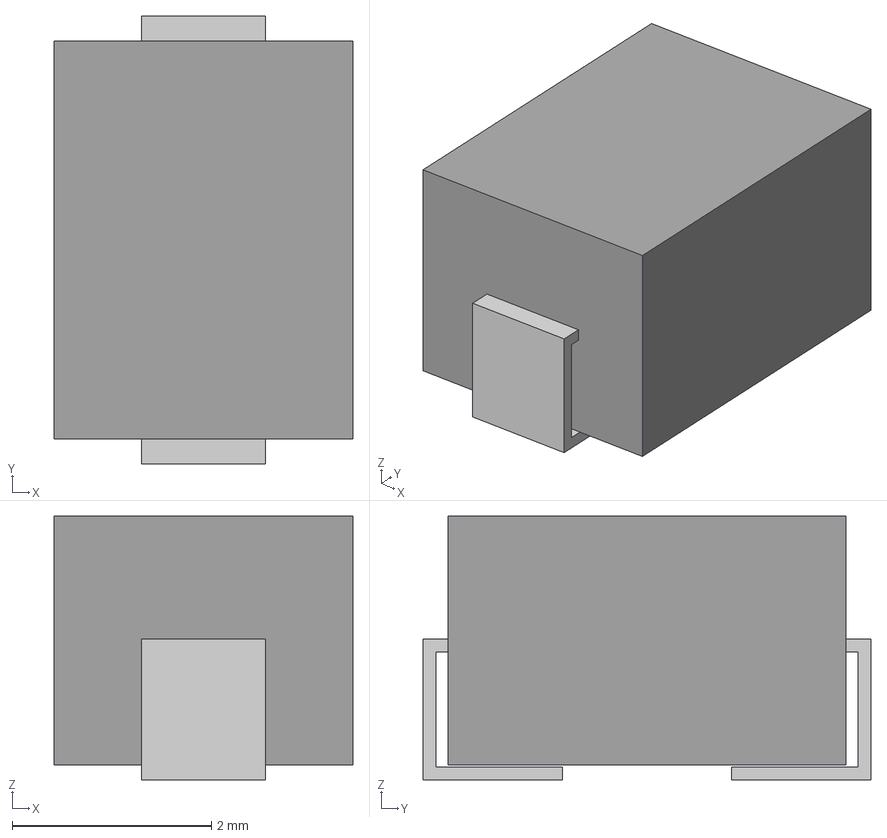
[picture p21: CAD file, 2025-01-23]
3d/fb4x3.step
3.00 x 4.50 x 2.65 mm
LinearExtrude004
LinearExtrude003
Matrix_Union

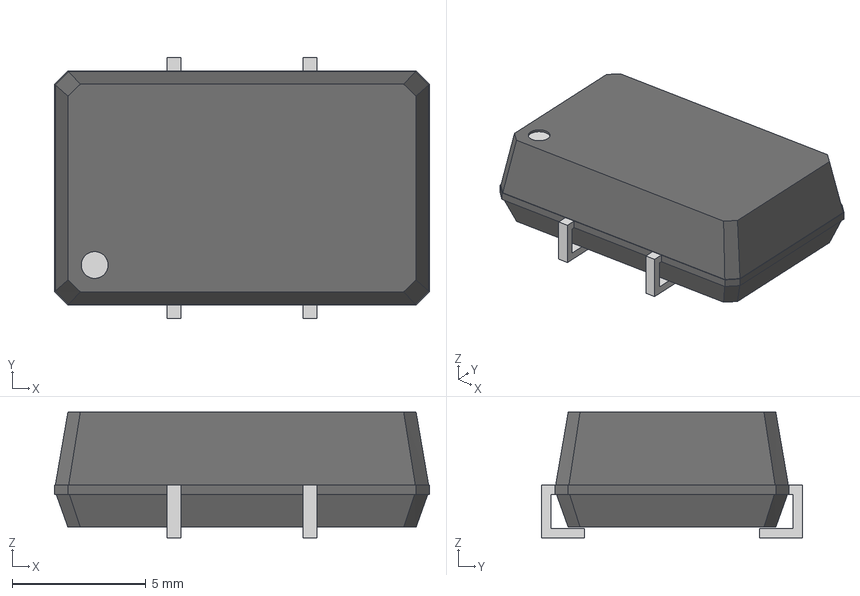
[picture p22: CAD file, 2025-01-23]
3d/sg615p.step
14.0 x 9.75 x 4.70 mm

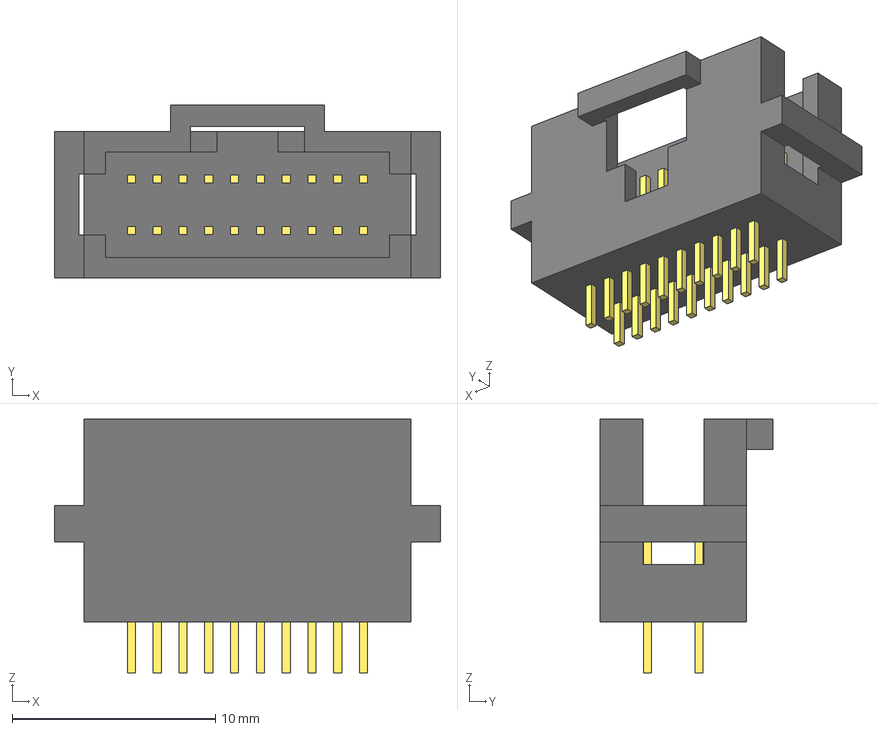
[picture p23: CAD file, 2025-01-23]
3d/2x10_vertical.step
19.0 x 8.50 x 12.5 mm

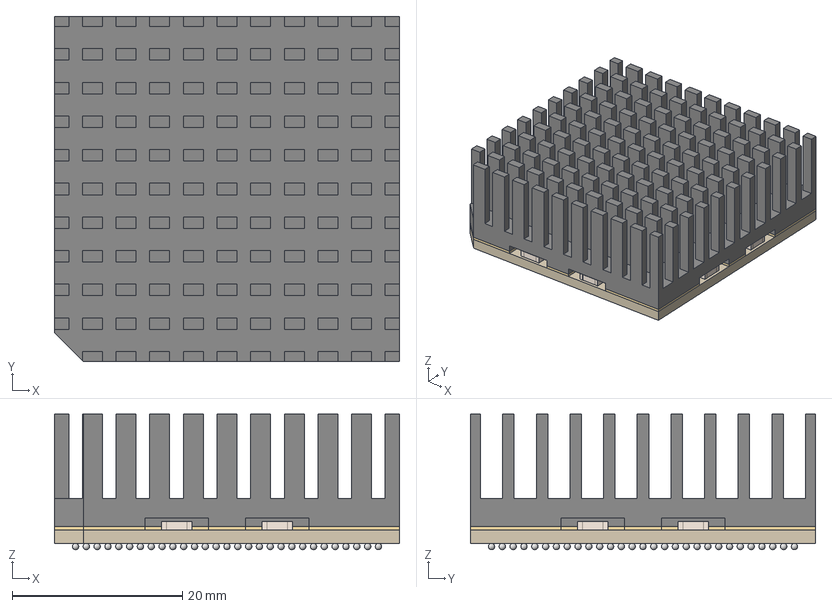
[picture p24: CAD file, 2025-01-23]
3d/bga479.step
40.5 x 40.5 x 15.9 mm
Matrix_Union011
Matrix_Union002
Matrix_Union005
Matrix_Union008
LinearExtrude001
LinearExtrude

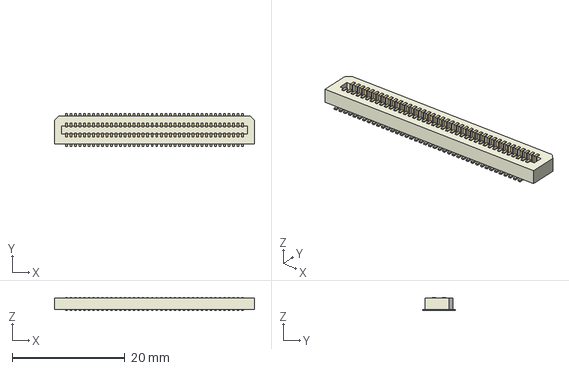
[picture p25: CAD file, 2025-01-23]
3d/3M_P08-080-SL-A-G.step
35.4 x 5.88 x 2.30 mm

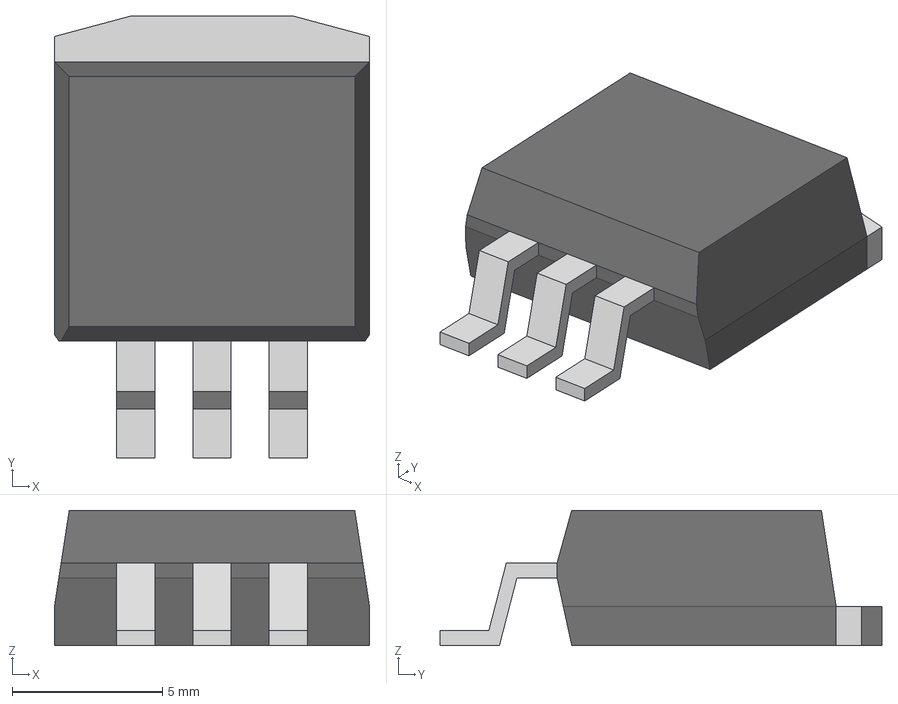
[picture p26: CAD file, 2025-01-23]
3d/to263-3.step
10.5 x 14.7 x 4.50 mm

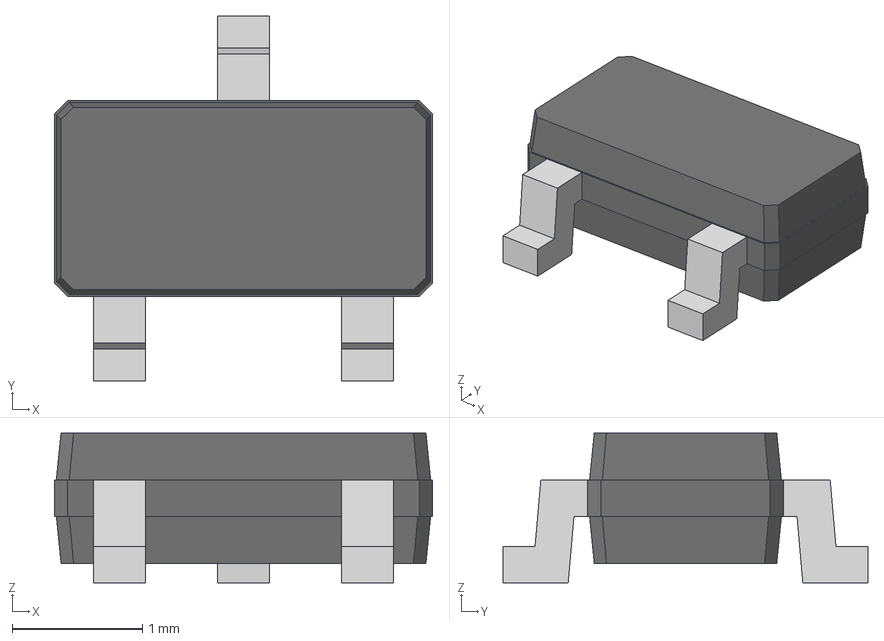
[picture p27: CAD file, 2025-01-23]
3d/sot23.step
2.90 x 2.80 x 1.15 mm
Matrix_Union
Matrix_Union001
LinearExtrude003

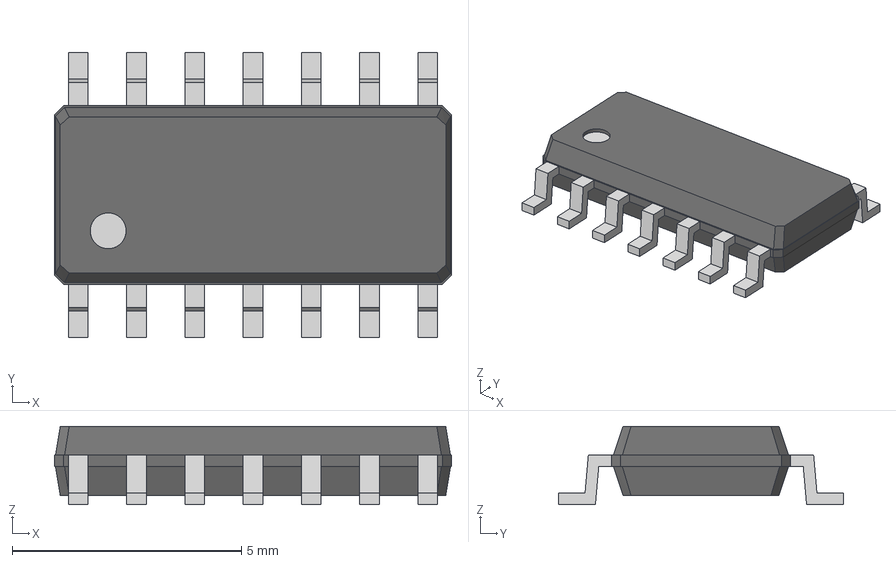
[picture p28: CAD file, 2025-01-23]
3d/soic14.step
8.65 x 6.20 x 1.70 mm

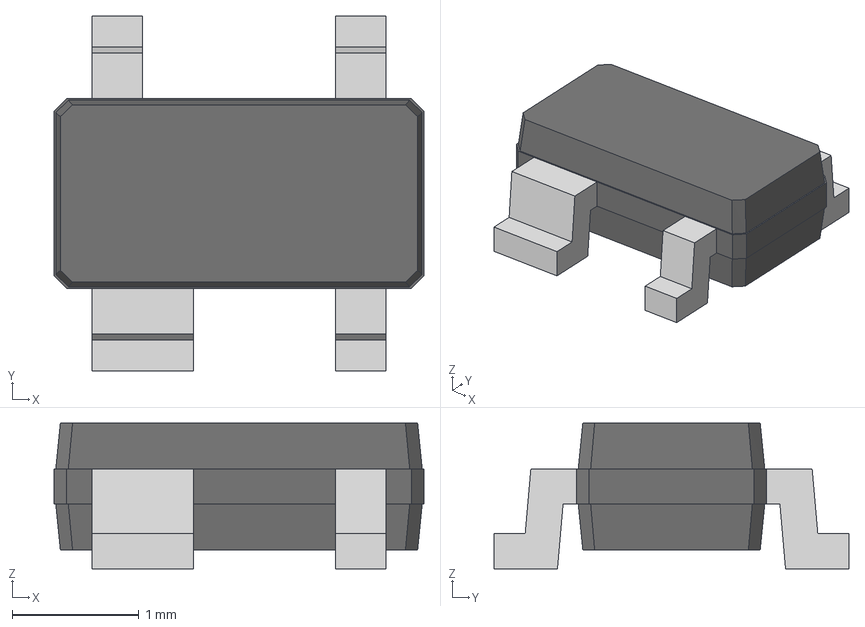
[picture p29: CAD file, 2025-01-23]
3d/sot143.step
2.92 x 2.80 x 1.15 mm
Matrix_Union
Matrix_Union001
LinearExtrude003
LinearExtrude004

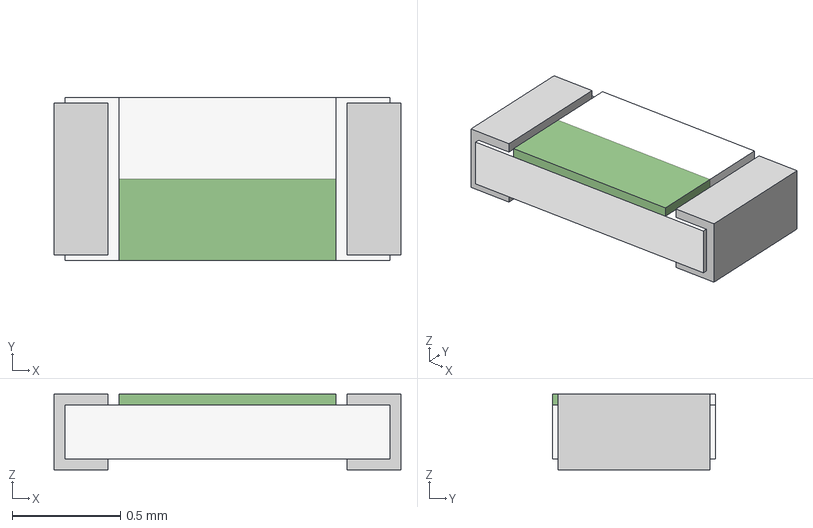
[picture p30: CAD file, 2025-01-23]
3d/f0603.step
1.60 x 0.75 x 0.35 mm

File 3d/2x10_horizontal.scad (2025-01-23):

pin_pitch_x = 1.27;
pin_pitch_y = 2.54;
pin_width = 0.4;
pin_height = 8.1-2.5;
pin_depth = 2.5;

shroud_width = 7.2;
shroud_length = 19;
shroud_height = 10;

pin_separator_length = 4;

inset_length = 16;
inset_height = 4.3;
inset_height2 = 4;

internal_width = 5.2;
internal_length = 14;
internal_height = 7.2;

clip_length = 16.6;
clip_width = 3;

index_offset = 6.5 - internal_width;
index_offset3 = 8.5 - shroud_width;
index_width1 = 3;
index_width2 = 5.6;
index_height2 = 4.8;
index_height3 = 1.5;

color("#222") union() translate([-pin_pitch_x * 6, 0, 0]) for (x = [0 : 12]) {
    translate([x * pin_pitch_x, 0, 0]) {
        translate([0, pin_separator_length/2, pin_height/2]) cube([pin_width*1.6, pin_separator_length+2.54, pin_height], center = true);
    }
}

color("#fd1") union() translate([-pin_pitch_x * 4.5, 1.05, 0]) for (x = [0 : 9]) {
    translate([x * pin_pitch_x, 0, 0]) {
        translate([0, pin_separator_length, (pin_height - 0.53 - pin_depth) / 2]) cube([pin_width, pin_width, pin_height + pin_depth - 0.53], center = true);
        translate([0, pin_separator_length-pin_pitch_y, (pin_height - 3.1 - pin_depth) / 2]) cube([pin_width, pin_width, pin_height + pin_depth - 3.1], center = true);
    }
}

color("#fd1") translate([0, 0, shroud_width/2]) rotate([90, 0, 0]) {
    translate([-pin_pitch_x * 4.5, 0, 0]) for (x = [0 : 9]) {
        translate([x * pin_pitch_x, 0, 0]) {
            translate([0, pin_pitch_y/2, (pin_height - pin_depth - 2.54) / 2]) cube([pin_width, pin_width, pin_height + pin_depth + 2.54], center = true);
            translate([0, -pin_pitch_y/2, (pin_height - pin_depth - 0.2) / 2]) cube([pin_width, pin_width, pin_height + pin_depth + 0.2], center = true);
        }
    }
}

color("#222") translate([0, 0, shroud_width/2]) rotate([90, 0, 0]) {
    difference() {
        union() {
            translate([0, 0, shroud_height/2]) cube([shroud_length, shroud_width, shroud_height], center = true);
            translate([0, shroud_width/2 + index_offset3/2, shroud_height - index_height3/2]) cube([index_width2 + 2, index_offset3, index_height3], center = true);
        }
        
        union() {
        translate([0, 0, shroud_height - internal_height/2 + 0.05]) cube([internal_length, internal_width, internal_height], center = true);
        translate([0, 0, shroud_height - internal_height/2 + 0.05]) cube([clip_length, clip_width, internal_height], center = true);
        
        inset_w = (shroud_length - inset_length)/2;
        inset_x = shroud_length/2 - inset_w/2;
        inset_y = shroud_height - inset_height/2;
        translate([-inset_x - 0.05, 0, inset_y + 0.05]) cube([inset_w, shroud_width + 1, inset_height], center = true);
        translate([inset_x + 0.05, 0, inset_y + 0.05]) cube([inset_w, shroud_width + 1, inset_height], center = true);
        
        inset_y2 = inset_height2/2;
        translate([-inset_x - 0.05, 0, inset_y2 - 0.05]) cube([inset_w, shroud_width + 1, inset_height2], center = true);
        translate([inset_x + 0.05, 0, inset_y2 - 0.05]) cube([inset_w, shroud_width + 1, inset_height2], center = true);
        
        translate([0, internal_width/2 + index_offset/2 - 0.05, shroud_height - internal_height/2 + 0.05]) cube([index_width1, index_offset, internal_height], center = true);
        translate([0, internal_width/2 + index_offset/2 - 0.05, shroud_height - index_height2/2 + 0.05]) cube([index_width2, index_offset, index_height2], center = true);
        }
    }
}

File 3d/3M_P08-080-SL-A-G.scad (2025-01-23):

body_width = 4.93;
body_length = 35.4;
body_height = 2.2;

overall_width = 5.88;

chamfer_length = 1.0;

pins = 80;
pin_pitch = 0.8;
pin_width = 0.35;
pin_thickness = 0.2;

color("#cca") difference() {
    translate([0, 0, pin_thickness]) linear_extrude(height = body_height - pin_thickness) {
        polygon([
            [-body_length/2, -body_width/2],
            [body_length/2, -body_width/2],
            [body_length/2, body_width/2 - sqrt(chamfer_length/2)],
            [body_length/2 - sqrt(chamfer_length/2), body_width/2],
            [-body_length/2 + sqrt(chamfer_length/2), body_width/2],
            [-body_length/2, body_width/2 - sqrt(chamfer_length/2)],
        ]);
    }
    
    translate([0, 0, body_height/2 + pin_thickness + 0.1]) cube([33, 1.5, body_height], center = true);
}

color("#fd1") translate([-pin_pitch * 19.5, 0, pin_thickness/2]) for (x = [0 : 39]) {
    translate([x * pin_pitch, 0, 0]) {
        cube([pin_width, overall_width, pin_thickness], center = true);
    
        translate([0, 0.9, body_height/2]) cube([pin_width, 0.75, body_height], center=true);
        translate([0, -0.9, body_height/2]) cube([pin_width, 0.75, body_height], center=true);
    }
}

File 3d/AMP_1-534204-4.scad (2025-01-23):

pin_pitch = 2.54;
pin_length = 3;
pin_offset_y = 7.87;
pin_width = 0.7;
pin_thickness = 0.3;

header_pin_diameter = 0.5;

overall_width = 98;
overall_height = 6;
shroud_height = 5.9;

shroud_center_z = overall_height - shroud_height + shroud_height/2;

upper_row_z = shroud_center_z + 1.27;
lower_row_z = shroud_center_z - 1.27;

front_pin_height = lower_row_z - header_pin_diameter/2;
back_pin_height = upper_row_z - header_pin_diameter/2;

$fn = 16;

for (x = [0 : 35]) {
    translate([x * -pin_pitch, 0, 0]) {
        translate([0, 0, -pin_length/2]) cube([pin_width, pin_thickness, pin_length], center = true);
        translate([0, 0, front_pin_height/2]) cube([pin_width, pin_thickness, front_pin_height], center = true);
        translate([0, pin_offset_y, -pin_length/2]) cube([pin_width, pin_thickness, pin_length], center = true);
        translate([0, pin_offset_y, back_pin_height/2]) cube([pin_width, pin_thickness, back_pin_height], center = true);
    }
}

// shroud
color("#531") difference() {
    translate([-17.5*pin_pitch, pin_offset_y/2, shroud_center_z]) cube([overall_width, pin_offset_y - pin_thickness*2, shroud_height], center = true);
    for (x = [0 : 35]) {
        translate([x * -pin_pitch, 0, 0]) {
            translate([0, pin_offset_y/2, upper_row_z]) cube([header_pin_diameter*2, pin_offset_y, header_pin_diameter*2], center = true);
            translate([0, pin_offset_y/2, lower_row_z]) cube([header_pin_diameter*2, pin_offset_y, header_pin_diameter*2], center = true);
        }
    }
    translate([-17.5*pin_pitch, 0, shroud_center_z]) {
        translate([overall_width / 2, 0, 0]) rotate([-90, 0, 0]) cylinder(h = pin_offset_y, r = 3.7/2);
        translate([-overall_width / 2, 0, 0]) rotate([-90, 0, 0]) cylinder(h = pin_offset_y, r = 3.7/2);
    }
}

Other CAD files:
3d/pqfp208.step
3d/oscillator_dip14.step
3d/fb_axial.step
3d/ssop14.step
3d/2x10_vertical.scad
3d/AMP_1-534204-4.step
3d/bga479.scad
3d/f0603.scad
3d/fb4x3.scad
3d/fb_axial.scad
3d/pod_connector.scad
3d/pod_connector.step
3d/pqfp208.scad
3d/qfp44.scad
3d/qfp44.step
3d/qfp52.scad
3d/qfp52.step
3d/sg615p.scad
3d/soic14.scad
3d/soic16.scad
3d/soic16.step
3d/soic16wr.scad
3d/soic16wr.step
3d/soic20w.scad
3d/soic20w.step
3d/soic8.scad
3d/sot143.scad
3d/sot23.scad
3d/ssop14.scad
3d/ssop64.scad
3d/to263-3.scad
3d/to263-5.scad
3d/to263-5.step
3d/to263heatsink.scad
3d/to263heatsink.step
3d/tqfp100.scad
3d/tqfp144.scad
3d/tqfp144.step

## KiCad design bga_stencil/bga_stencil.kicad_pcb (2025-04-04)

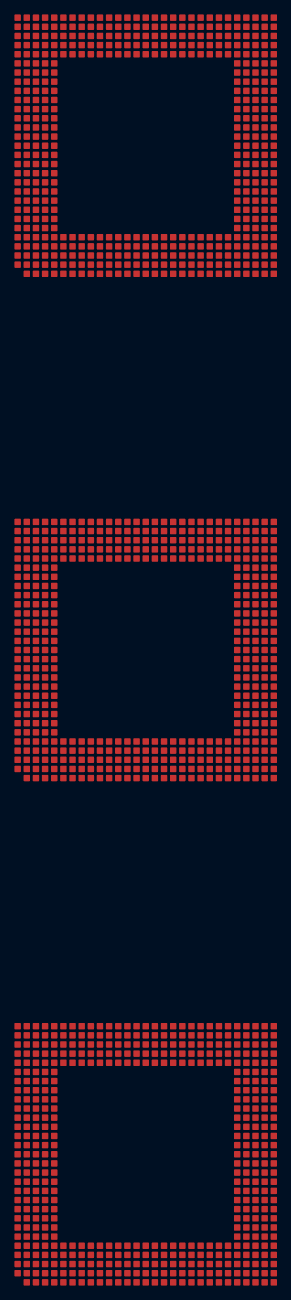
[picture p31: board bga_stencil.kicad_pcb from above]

Board: 2 copper layers, 3 parts (0 on the bottom side), 2 nets, no tracks yet.

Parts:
U1, U2, U3: 1821-3936; BGA-479_40.5mm_P1.27mm_Stencil

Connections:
+3.3V: U1.A3 (+3.3V), U1.A5 (+3.3V), U1.A10 (+3.3V), U1.A11 (+3.3V), U1.A14 (+3.3V), U1.A16 (+3.3V), U1.A19 (+3.3V), U1.A20 (+3.3V), U1.A27 (+3.3V), U1.A29 (+3.3V), U1.AA1 (+3.3V), U1.AB3 (+3.3V), U1.AB29 (+3.3V), U1.AC1 (+3.3V), U1.AC3 (+3.3V), U1.AC5 (+3.3V), U1.AC10 (+3.3V), U1.AC11 (+3.3V), U1.AC14 (+3.3V), U1.AC16 (+3.3V), U1.AC19 (+3.3V), U1.AC20 (+3.3V), U1.AC27 (+3.3V), U1.AC29 (+3.3V), U1.B2 (+3.3V), U1.C1 (+3.3V), U1.C29 (+3.3V), U1.J1 (+3.3V), U1.J29 (+3.3V), U1.K1 (+3.3V), U1.K29 (+3.3V), U1.N1 (+3.3V), U1.N29 (+3.3V), U1.P1 (+3.3V), U1.R29 (+3.3V), U1.S1 (+3.3V), U1.S29 (+3.3V), U1.T1 (+3.3V), U1.T29 (+3.3V), U1.W29 (+3.3V), U2.A3 (+3.3V), U2.A5 (+3.3V), U2.A10 (+3.3V), U2.A11 (+3.3V), U2.A14 (+3.3V), U2.A16 (+3.3V), U2.A19 (+3.3V), U2.A20 (+3.3V), U2.A27 (+3.3V), U2.A29 (+3.3V), U2.AA1 (+3.3V), U2.AB3 (+3.3V), U2.AB29 (+3.3V), U2.AC1 (+3.3V), U2.AC3 (+3.3V), U2.AC5 (+3.3V), U2.AC10 (+3.3V), U2.AC11 (+3.3V), U2.AC14 (+3.3V), U2.AC16 (+3.3V), U2.AC19 (+3.3V), U2.AC20 (+3.3V), U2.AC27 (+3.3V), U2.AC29 (+3.3V), U2.B2 (+3.3V), U2.C1 (+3.3V), U2.C29 (+3.3V), U2.J1 (+3.3V), U2.J29 (+3.3V), U2.K1 (+3.3V), U2.K29 (+3.3V), U2.N1 (+3.3V), U2.N29 (+3.3V), U2.P1 (+3.3V), U2.R29 (+3.3V), U2.S1 (+3.3V), U2.S29 (+3.3V), U2.T1 (+3.3V), U2.T29 (+3.3V), U2.W29 (+3.3V), U3.A3 (+3.3V), U3.A5 (+3.3V), U3.A10 (+3.3V), U3.A11 (+3.3V), U3.A14 (+3.3V), U3.A16 (+3.3V), U3.A19 (+3.3V), U3.A20 (+3.3V), U3.A27 (+3.3V), U3.A29 (+3.3V), U3.AA1 (+3.3V), U3.AB3 (+3.3V), U3.AB29 (+3.3V), U3.AC1 (+3.3V), U3.AC3 (+3.3V), U3.AC5 (+3.3V), U3.AC10 (+3.3V), U3.AC11 (+3.3V), U3.AC14 (+3.3V), U3.AC16 (+3.3V), U3.AC19 (+3.3V), U3.AC20 (+3.3V), U3.AC27 (+3.3V), U3.AC29 (+3.3V), U3.B2 (+3.3V), U3.C1 (+3.3V), U3.C29 (+3.3V), U3.J1 (+3.3V), U3.J29 (+3.3V), U3.K1 (+3.3V), U3.K29 (+3.3V), U3.N1 (+3.3V), U3.N29 (+3.3V), U3.P1 (+3.3V), U3.R29 (+3.3V), U3.S1 (+3.3V), U3.S29 (+3.3V), U3.T1 (+3.3V), U3.T29 (+3.3V), U3.W29 (+3.3V)
GND: U1.A2 (GND), U1.A4 (GND), U1.A7 (GND), U1.A8 (GND), U1.A9 (GND), U1.A12 (GND), U1.A15 (GND), U1.A18 (GND), U1.A21 (GND), U1.A22 (GND), U1.A23 (GND), U1.A25 (GND), U1.A26 (GND), U1.A28 (GND), U1.AA29 (GND), U1.AB1 (GND), U1.AB2 (GND), U1.AB28 (GND), U1.AC2 (GND), U1.AC4 (GND), U1.AC7 (GND), U1.AC8 (GND), U1.AC9 (GND), U1.AC12 (GND), U1.AC15 (GND), U1.AC18 (GND), U1.AC21 (GND), U1.AC22 (GND), U1.AC23 (GND), U1.AC25 (GND), U1.AC26 (GND), U1.AC28 (GND), U1.B1 (GND), U1.B29 (GND), U1.D1 (GND), U1.D29 (GND), U1.E1 (GND), U1.E29 (GND), U1.G1 (GND), U1.G29 (GND), U1.H1 (GND), U1.H29 (GND), U1.I1 (GND), U1.I29 (GND), U1.L1 (GND), U1.L29 (GND), U1.O1 (GND), U1.O29 (GND), U1.P29 (GND), U1.R1 (GND), U1.U1 (GND), U1.U29 (GND), U1.V1 (GND), U1.V29 (GND), U1.W1 (GND), U1.Y1 (GND), U1.Y29 (GND), U1.Z1 (GND), U1.Z29 (GND), U2.A2 (GND), U2.A4 (GND), U2.A7 (GND), U2.A8 (GND), U2.A9 (GND), U2.A12 (GND), U2.A15 (GND), U2.A18 (GND), U2.A21 (GND), U2.A22 (GND), U2.A23 (GND), U2.A25 (GND), U2.A26 (GND), U2.A28 (GND), U2.AA29 (GND), U2.AB1 (GND), U2.AB2 (GND), U2.AB28 (GND), U2.AC2 (GND), U2.AC4 (GND), U2.AC7 (GND), U2.AC8 (GND), U2.AC9 (GND), U2.AC12 (GND), U2.AC15 (GND), U2.AC18 (GND), U2.AC21 (GND), U2.AC22 (GND), U2.AC23 (GND), U2.AC25 (GND), U2.AC26 (GND), U2.AC28 (GND), U2.B1 (GND), U2.B29 (GND), U2.D1 (GND), U2.D29 (GND), U2.E1 (GND), U2.E29 (GND), U2.G1 (GND), U2.G29 (GND), U2.H1 (GND), U2.H29 (GND), U2.I1 (GND), U2.I29 (GND), U2.L1 (GND), U2.L29 (GND), U2.O1 (GND), U2.O29 (GND), U2.P29 (GND), U2.R1 (GND), U2.U1 (GND), U2.U29 (GND), U2.V1 (GND), U2.V29 (GND), U2.W1 (GND), U2.Y1 (GND), U2.Y29 (GND), U2.Z1 (GND), U2.Z29 (GND), U3.A2 (GND), U3.A4 (GND), U3.A7 (GND), U3.A8 (GND), U3.A9 (GND), U3.A12 (GND), U3.A15 (GND), U3.A18 (GND), U3.A21 (GND), U3.A22 (GND), U3.A23 (GND), U3.A25 (GND), U3.A26 (GND), U3.A28 (GND), U3.AA29 (GND), U3.AB1 (GND), U3.AB2 (GND), U3.AB28 (GND), U3.AC2 (GND), U3.AC4 (GND), U3.AC7 (GND), U3.AC8 (GND), U3.AC9 (GND), U3.AC12 (GND), U3.AC15 (GND), U3.AC18 (GND), U3.AC21 (GND), U3.AC22 (GND), U3.AC23 (GND), U3.AC25 (GND), U3.AC26 (GND), U3.AC28 (GND), U3.B1 (GND), U3.B29 (GND), U3.D1 (GND), U3.D29 (GND), U3.E1 (GND), U3.E29 (GND), U3.G1 (GND), U3.G29 (GND), U3.H1 (GND), U3.H29 (GND), U3.I1 (GND), U3.I29 (GND), U3.L1 (GND), U3.L29 (GND), U3.O1 (GND), U3.O29 (GND), U3.P29 (GND), U3.R1 (GND), U3.U1 (GND), U3.U29 (GND), U3.V1 (GND), U3.V29 (GND), U3.W1 (GND), U3.Y1 (GND), U3.Y29 (GND), U3.Z1 (GND), U3.Z29 (GND)

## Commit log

2024-12-22 hello, original
    [acquisition.kicad_sch, board_stacking.kicad_sch, board_stacking_left.kicad_sch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]
2025-01-01 redux work
    [acquisition.kicad_sch, redux.kicad_sch, zoom.kicad_sch]
2025-01-02 replace SOIC resistor arrays
    [redux.kicad_sch]
2025-01-05 Rework acquisition ASIC routing
    [acquisition.kicad_sch, redux.kicad_sch, zoom.kicad_sch]
2025-01-06 length matching & rounded tracks
    [redux.kicad_sch]
2025-01-07 Clean up FPGA, zoom CS routing
    [redux.kicad_sch]
2025-01-18 Remove bottom soldermask over BGA vias to facilitate verification of reflow (check for diode drop on I/Os)
2025-01-19 improve routing around fpga
    [redux.kicad_sch]
2025-01-19 Allow alternate footprints for FPGA oscillator
    [redux.kicad_sch]
2025-01-23 3D models
    [2x10_horizontal.scad, 2x10_horizontal.step, 2x10_vertical.scad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]
2025-01-24 fix original version ECL routing to ASICs
    [acquisition.kicad_sch, original.kicad_sch, zoom.kicad_sch]
2025-01-31 clean up routing & add test points on original design
    [acquisition.kicad_sch, board_stacking.kicad_sch, board_stacking_left.kicad_sch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]
2025-01-31 Fix SY89421V pin 9 held low instead of floating
    [probe_cable.kicad_sch, redux.kicad_sch]
2025-02-05 rev 0 (submitted to jlc)
    [redux.kicad_sch]
2025-02-23 rev 1 (submitted to jlc)
    [acquisition.kicad_sch]
2025-04-04 BGA stencil, ASIC & DRAM bringup notes
    [bga_stencil.kicad_pcb, bga_stencil.kicad_sch]
2025-04-04 fix typos, remove LFS filters from .gitattributes
